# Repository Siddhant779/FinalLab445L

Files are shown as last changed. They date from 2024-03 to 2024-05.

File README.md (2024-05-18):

Review Assignment Due Date (https://classroom.github.com/a/83gqoQ2Z)
# ECE445L Final Lab
## Link to award won - Spring 2024
https://github.com/ECE445L/ECE445L-Winners
## Deliverables

The deliverables folder should contain documentation about your project as
outlined in the lab documents.

## HW

The hw folder should contain your schematic and board files for your PCB or
circuits. In labs 3-11, you will be creating schematics for your circuit
in EAGLE. A setup tutorial can be found
[here](https://www.shawnvictor.net/autodesk-eagle.html).

## SW

The sw folder should contain your application firmware and software written for
the lab. The sw/inc folder contains firmware drivers written for you by
Professor Valvano. Feel free to write your own (in fact, in some labs, you may
be required to write your own).

You can place any other source files in the sw/ folder. TAs will look at the
files you create and/or modify for software quality and for running your
project.

## Resources

A couple files are provided in the Resources folder so you don't have to keep
searching for that one TI document. Some of them are immediately useful, like
the TM4C datasheet. Others may be useful for your final project, like the
TM4C_System_Design_Guidelines page.

## Git and Github

We will extensively use Git and Github for managing lab projects. This makes it
easier for TAs to grade and help debug the project by allowing the students to
see commit histories, maintain a common project structure, collaborate with
partners, merge different codebases, and to debug work.

Two common ways of using Git and Github are [Github Desktop](https://desktop.github.com/) and the [command line](https://git-scm.com/downloads). [Tutorials](https://dev.to/mollynem/git-github--workflow-fundamentals-5496) are also abundant on the net for you to peruse. We've provided a cheatsheet for git in the Resources folder.

It is highly recommended to make the most out of Git, even if you've never used
it before. Version control will save you a lot of suffering, and tools like Git
or SVN are ubiquitous in the industry.

## Lab Report

Following the lab doc provided at the root of this project, the TAs request you
submit a lab report in Microsoft Word (or Pages, if you're a Mac user). Please
name it `EID_lab_LAB_NUMBER_report.pdf`. Templates are provided in the root dir.

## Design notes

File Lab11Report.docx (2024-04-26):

Name: __ Prithvi Senthilkumar, Joon Song, Siddhant Pandit, Wyatt Cole

EID: __ ps33536_hjs2235_shp695_wtc534

Semester: Spring 2024

Course: ECE445L

A) Objectives:

1. In a few sentences, describe the purpose of the lab.

Purpose is to design an embedded system that can fit in an enclosure. We are building the Tpod, which is an Ipod like music player that stores song in an SD card, plays songs through headphones, and has touch display and can send messages over wifi. This lab builds the PCB for the system

B) Hardware Design Deliverables:

1. N/A

C) Software Design Deliverables:

1. I have pushed my project to GitHub for grading (Yes/No):
2. Deliverable 1: System design diagram of the modules created.

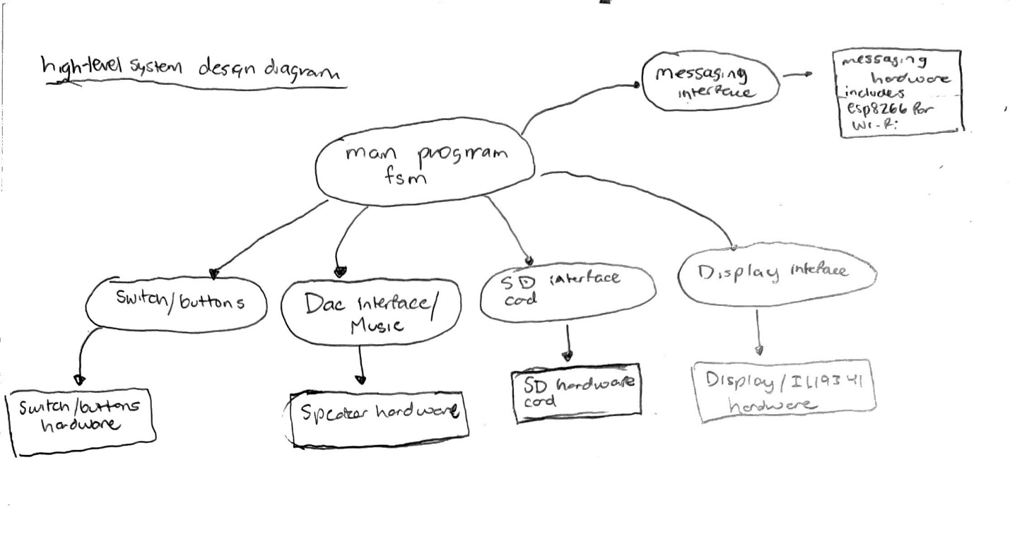
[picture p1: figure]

D) General Deliverables:

1. Deliverable 2: Software Tests

Based on our design diagram, we had separate tests for each module. For the dis-play, to test our initialization function we built a basic circuit to connect our TM4C to the ILI9341 screen, and see if basic functions such as drawing pixels work on the screen. After that, we added draw and outString functions for our project. For the SD card, we wrote basic code for reading from a txt file and outputting the values that we read on the screen. Furthermore, for sound we first tested the sound with individual notes, then moved on to reading from a music array that was set as a constant within the program. Lastly for mes-saging, we tested the server by using dummy clients and sending messages. Along that same line we tested sending from the TM4C by matching the message to what was received by the server and what was sent by the TM4C. We tested receiving by matching the mes-sage that was displayed by the TM4C to what was sent by the server. For integration tests, we used the same tests for each module as we integrated each module with each other. We first integrated display with SD card, then sound, then buttons and last-ly messaging, and tested each module with the tests described above at every step.

2. Deliverable 3: Hardware Tests

Tested all the board voltages with a multimeter to make sure power worked.

Tested audio software test on PCB to make sure headphone jack worked.

Tested wifi communication on PCB to make sure it worked same as breakboard.

Tested potentiometer to make sure it worked for ADC on PCB.

Multiple iterations of enclosure to make sure PCB fits and buttons can be pressed

3. Deliverable 4: Power consumption

Launchpad Base – 86 mA * 5V = 430 mW

Screen - 25 mA active * 3.3V = 75 mW

Music – 14-144 mA volume range * 5V = 70-720 mW

ESP –78 mA active * 3.3V = 257.4 mW active

Total – 1.482W when music active, .832.4 W when music passive

4. Deliverable 5 (10pt EC): Characterization of the system N/A

E) Analysis and Discussion Questions:

1. N/A

Lab 6 report ECE445L

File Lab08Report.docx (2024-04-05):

Name: __ Prithvi Senthilkumar, Joon Song, Siddhant Pandit, Wyatt Cole

EID: __ ps33536_hjs2235_shp695_wtc534

Semester: Spring 2024

Course: ECE445L

A) Objectives:

1. In a few sentences, describe the purpose of the lab.

Purpose is to design an embedded system that can fit in an enclosure. We are building the Tpod, which is an Ipod like music player that stores song in an SD card, plays songs through headphones, and has touch display and can send messages over wifi. This lab builds the PCB for the system

B) Hardware Design Deliverables:

1. Deliverable 1: Using KiCad, create a schematic for your design. Include a screenshot in the space below.

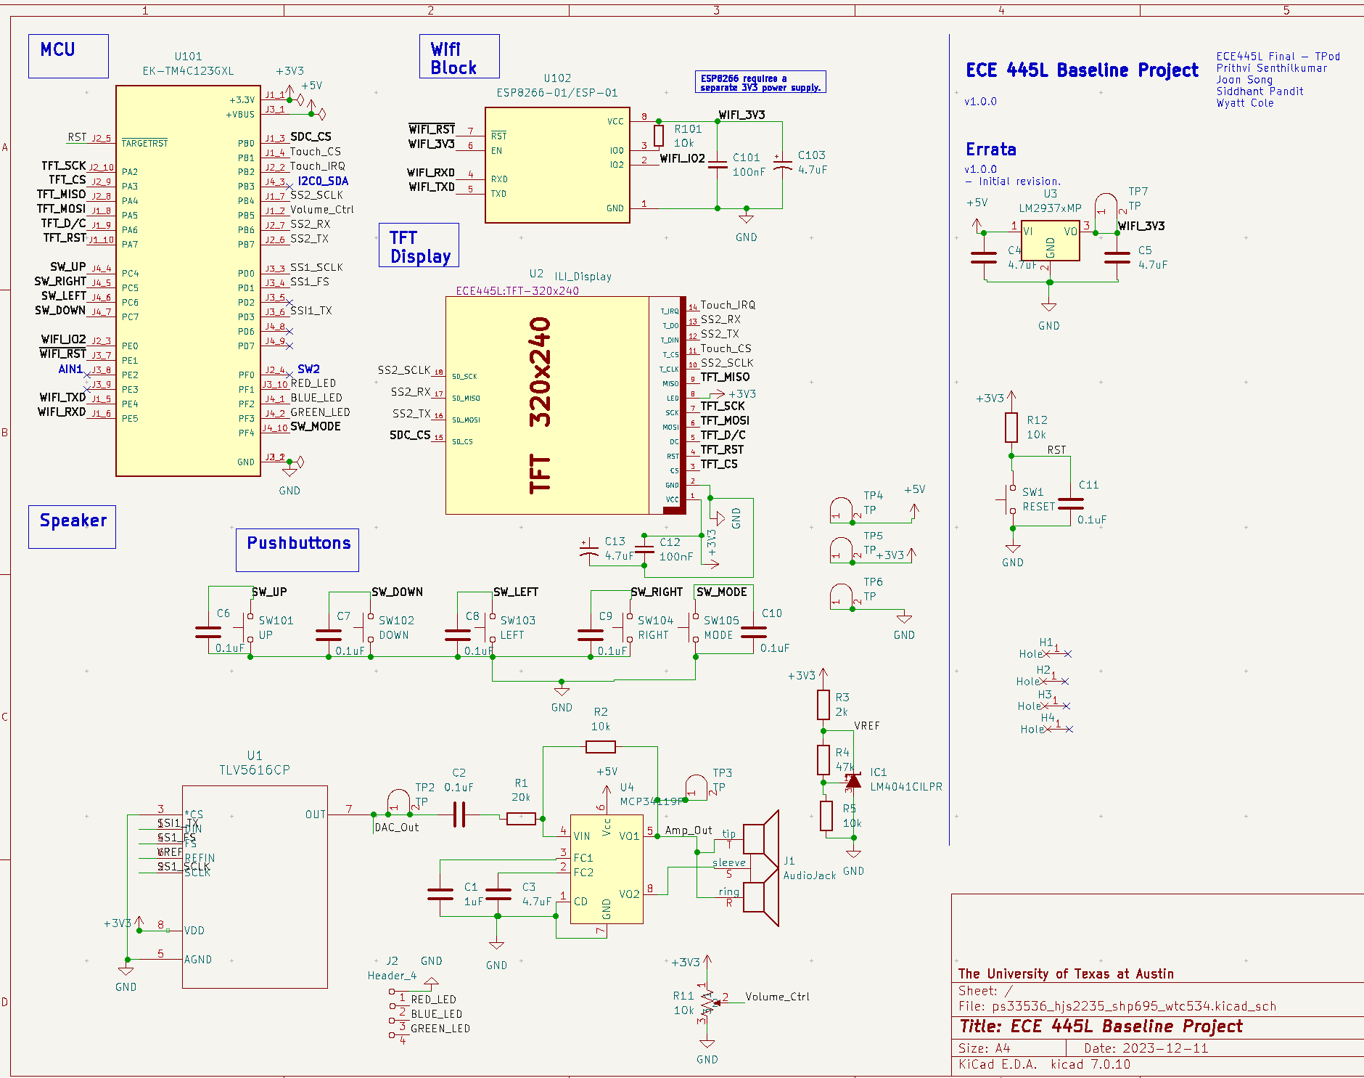
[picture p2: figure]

2. Deliverable 2: Using KiCad, create a Layout for your design. Include a screenshot in the space below.

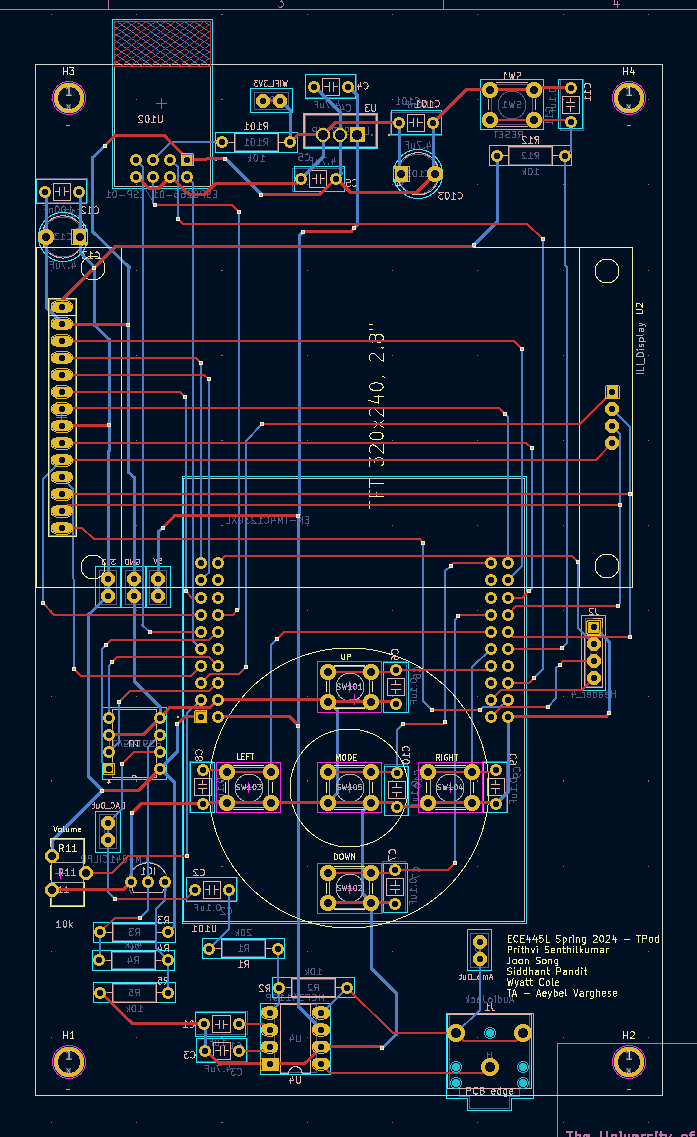
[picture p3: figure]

C) Software Design Deliverables:

1. I have pushed my project to GitHub for grading (Yes/No):
2. Deliverable 3: System design diagram of the modules created.

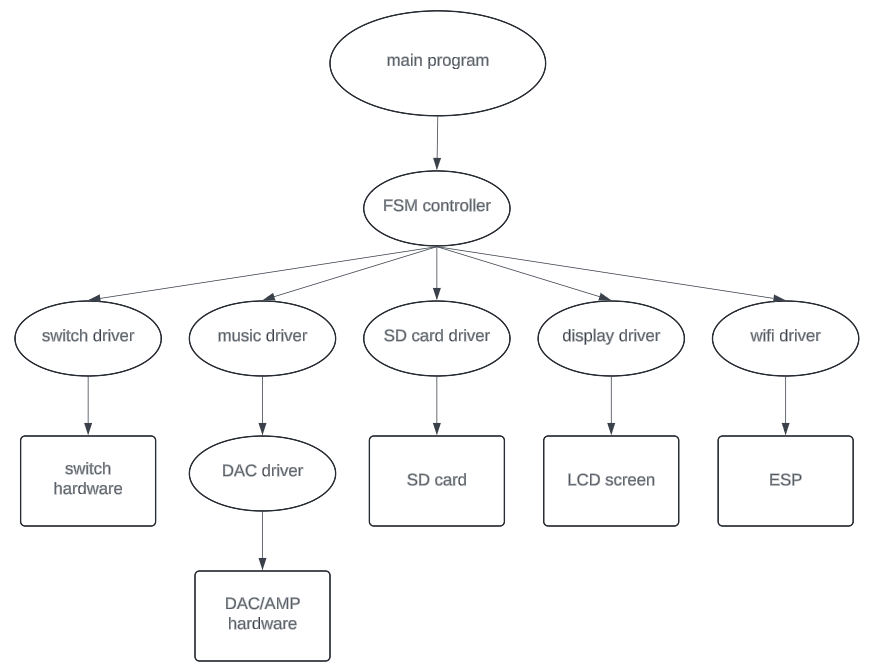
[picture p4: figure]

D) General Deliverables:

1. Deliverable 4: Total cost estimate
2. I have updated the bill of materials (Yes/No):
4. Out of pocket costs: $21
5. Adjusted competition costs: $21
6. Deliverable 5: Description of tests added for lab 8

Wifi test – connect ESP to python server to test sending and receiving messages

Sound test – Testing potentiometer ADC input to control volume through software

LCD display test – Write drivers to display to create lines and text

Integration test – Make all 3 of these work at same time

7. Deliverable 6 (10pt EC): Discrete IC usage N/A
8. Deliverable 7 (10pt EC): Characterization of the system N/A

E) Analysis and Discussion Questions:

1. What is the required naming scheme of the PCB submitted to us for review and ordering?

ps33536_hjs2235_shp695_wtc534.kicad_pro

and same for pcb and schematic files

Lab 8 report ECE445L

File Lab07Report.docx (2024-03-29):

Name: __Prithvi Senthilkumar, Joon Song, Siddhant Pandit, Wyatt Cole

EID: __ps33536_hjs2235_shp695_wtc534

Semester: Spring 2024

Course: ECE445L

A) Objectives:

1. In a few sentences, describe the purpose of the lab:

Purpose is to design an embedded system that can fit in an enclosure. We are building the Tpod, which is an Ipod like music player that stores song in an SD card, plays songs through headphones, and has touch display and can send messages over wifi.

B) Hardware Design Deliverables:

1. Deliverable 1: Using KiCad, create a schematic for your design. Include a screenshot in the space below.

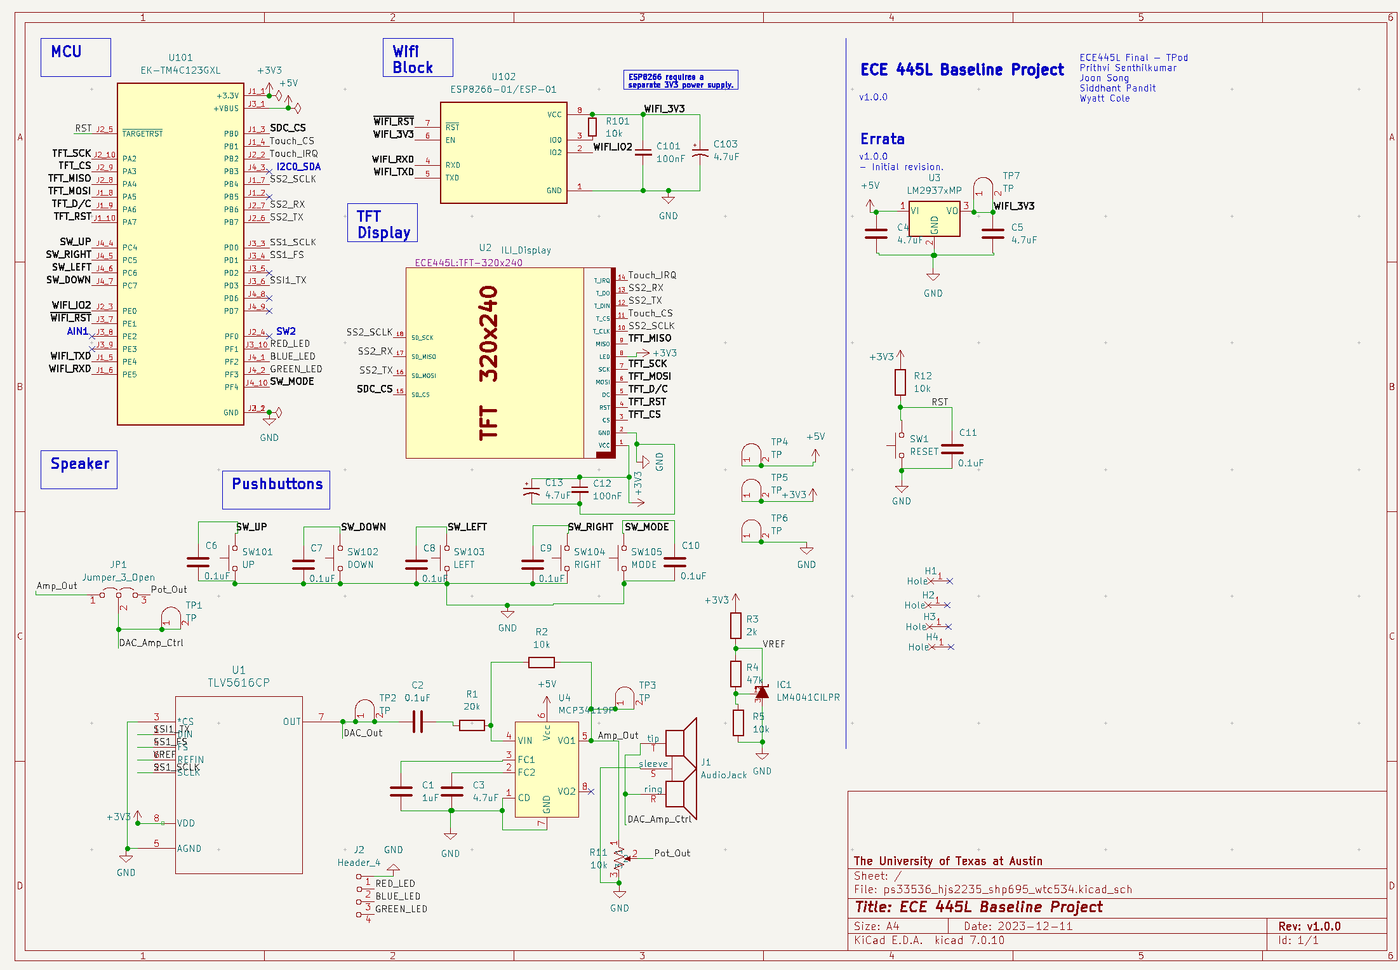
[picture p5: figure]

2. Deliverable 2: Using KiCad, create a Layout for your design. Include a screenshot in the space below.

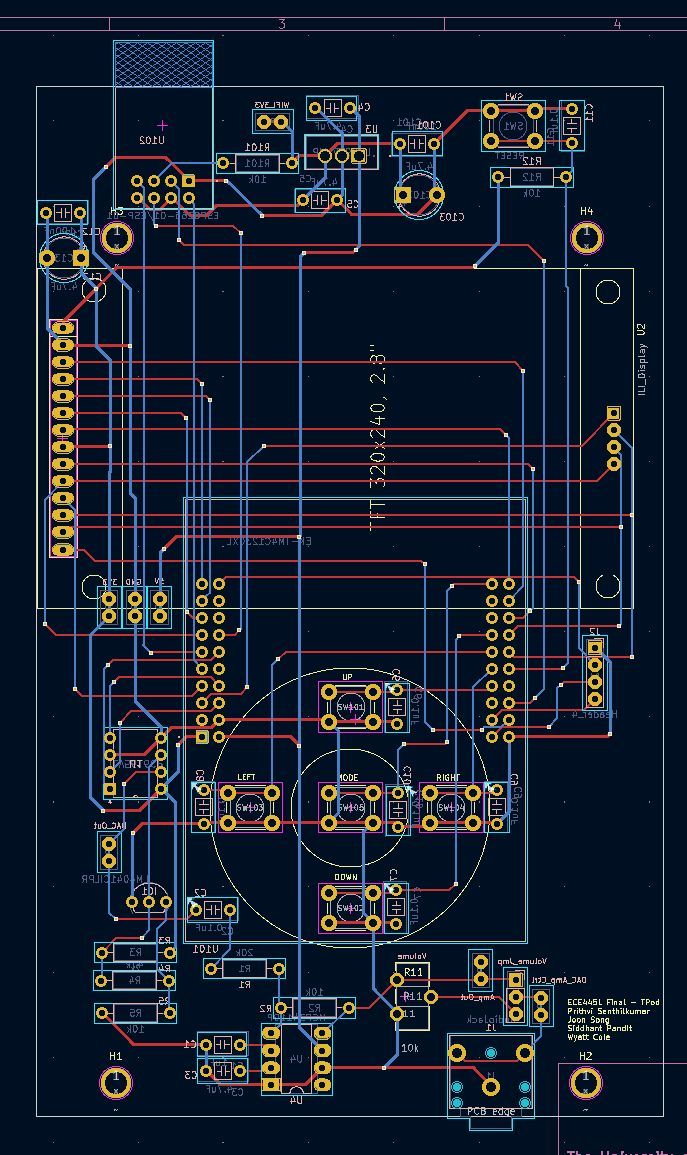
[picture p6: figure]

C) Software Design Deliverables:

1. I have pushed my project to GitHub for grading (Yes/No):
2. Deliverable 3: System design diagram of the modules created.


D) Deliverables:

1. Deliverable 4: Total cost estimate

I have updated the bill of materials (Yes/No):

Out of pocket costs: $21

Adjusted competition costs: $21

2. Deliverable 5: Estimated current usage

Launchpad Base – 86 mA

Screen - 25 mA active

Music – 14-144 mA volume range

ESP –78 mA active

Total – 333 mA max

3. Deliverable 6 (5pt EC): TIW Training

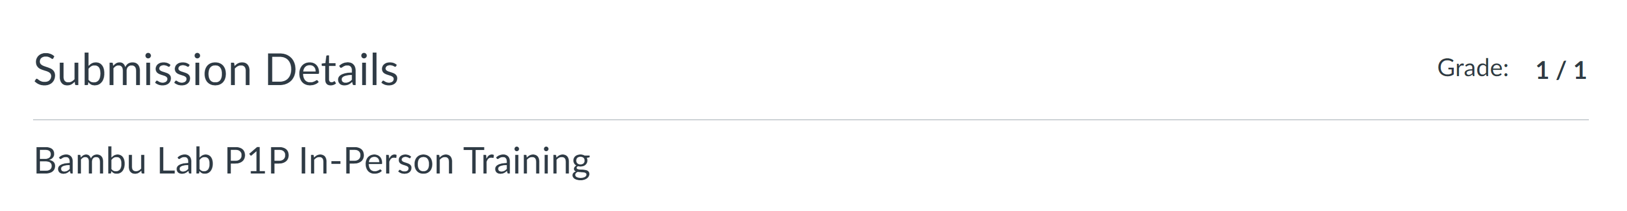
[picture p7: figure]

4. Deliverable 7 (10pt EC): Discrete IC usage N/A
5. Deliverable 8 (10pt EC): Characterization of the system N/A

E) Analysis and Discussion Questions:

1. How did you debug your system? How intrusive was it?

We mostly focused on isolating the sound and button modules, we wrote a tester main to make sure we could read from a wav file to play music, and testing button presses to make sure the controls worked. It was non-intrusive testing since we tested the functionality of the system in real time without any debugging instruments.

2. What’s the difference between unit testing, integration testing, and functional testing?

Unit testing tests individual units, integration testing tests interaction between units, functional testing is for the overall system as specified by the end user.

Lab 7 report ECE445L

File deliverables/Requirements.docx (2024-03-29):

## Project Requirements Document:

1) Overview
  a) Objectives: Why are we doing this project? What is the purpose?

Purpose is to design an embedded system that can fit in an enclosure. Test interactions of multiple HW and software modules

  b) Interactions with Existing Systems: Include this if you are connecting to another board

Will connect to another board to pass messages using TCP sockets with the ESP2866

  c) Terminology: Define domain specific terms used in the document.

Tpod – name of the embedded systems device

ILI9341 – name of the display

2) Functional Description
  a) Functionality: What will the system do precisely?

We are building the Tpod, which is an Ipod like music player that stores song in an SD card, plays songs through headphones, and has touch display and can send messages over wifi.

  b) Performance: Define the measures and describe how they will be determined.

Performance well if song can be played in real time, latency for display interactions is under 0.2 seconds, wifi can send messages through the server within 10 seconds.

  c) Usability: Describe the interfaces. Be quantitative if possible

Wifi interface will interact with server to handle message passing.

Menu interface to navigate features across the Tpod

5 button interface to navigate the menu

Possible touch screen interface to navigate menu

SD card interface to store songs to play

Audio interface with DAC, amp, and headphone jack to play the stored songs

3) Deliverables
  a) Roles and Responsibilities: Who will do what? What is the purpose?

Prithvi does PCB and enclosure

Wyatt does music, sound and buttons

Siddhant does ILI9341 display drivers and SD card interface

Joon does wifi communication protocols and message server

  b) Reports: Simply state the reports for Labs 7 and 11 will be written

Lab 7 report is written

  c) Outcomes: What are the deliverables? How do we know when it is done?

Project is done when each interface is completed and works concurrently with the menu. It is done when each module can perform together and still meet the end user latency requirements

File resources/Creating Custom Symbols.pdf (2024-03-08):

## Creating Custom Symbols

## Contents

Creating Custom Symbols | 1

Introduction

KiCad is a powerful open-source software suite for electronic design automation (EDA). It offers a comprehensive set of tools for schematic capture and PCB layout. While KiCad comes with an extensive library of symbols and footprints, there are times when you may need to create custom symbols and footprints to suit specific components or devices not available in the standard libraries or online.

Creating custom symbols allows you to represent components accurately in your schematics, while custom footprints enable precise placement and routing of PCB components.

Creating a Custom Symbol

A symbol in KiCad represents a component on your schematic. Every component on a schematic must be precisely represented to ensure the functionality and reliability of the final product. While KiCad offers a vast library of pre-made symbols, there are instances where designers encounter unique components or specialized devices not covered by the standard offerings.

To create a symbol, open the symbol editor.

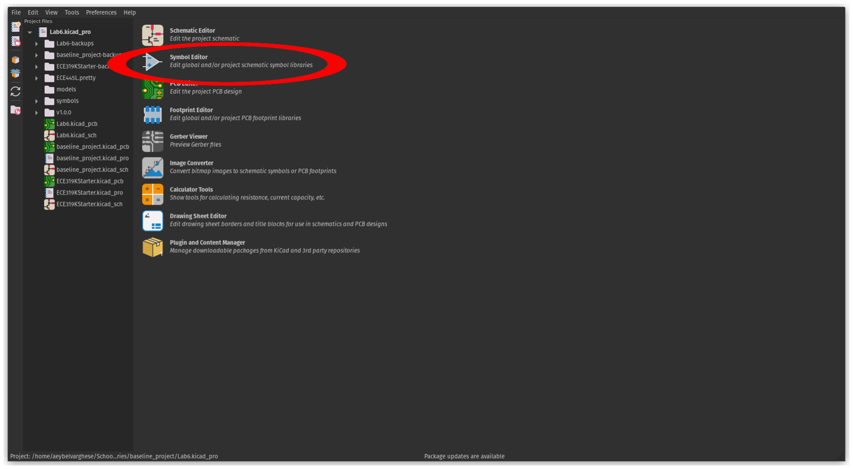
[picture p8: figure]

Figure 1: Main Menu

The KiCad Symbol Editor is a tool within the KiCad software suite specifically designed for creating and editing schematic symbols. It provides a user-friendly interface for designing graphical representations of electronic components, which are then used in schematics to illustrate circuit connections and layouts.

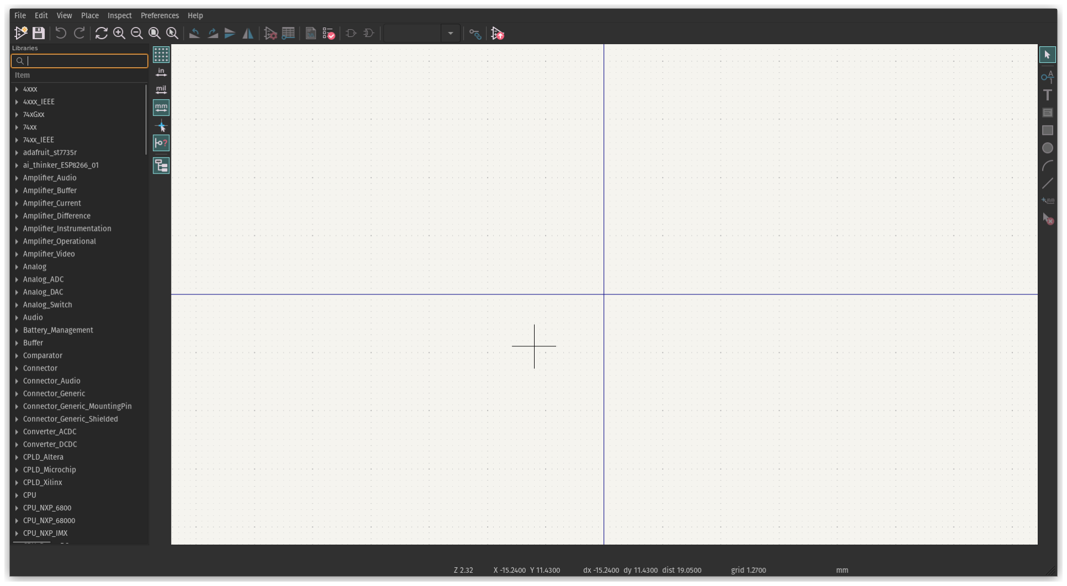
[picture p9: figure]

Figure 2: KiCad Symbol Editor

The Symbol Editor offers a graphical canvas where users can draw and manipulate schematic symbols using various drawing tools such as lines, arcs, polygons, and text boxes. The Symbol Editor allows users to save custom symbols to libraries for future use in other projects. Libraries can be organized and managed within KiCad to ensure easy access to custom symbols and efficient reuse across designs. Refer to the resource on adding libraries on more information regarding libraries.

When creating a symbol, it must be part of a library. We can either select a library to append a symbol to, or create a new library. To create a library, navigate to File → New Library, from here we can decide which symbol library table we want to add to, the global or project.

The global library table is shared amongst all your KiCad projects, while the project table is only for your currently open project. For this writeup, I am going to be adding it to the Project Table. When you press Ok, you can choose the location to save the “.kicad_sym” file which will contain your symbol library. You can choose any location you wish, although it is reccomended to have a folder dedicated for symbols organized in a reasonable matter. There is a “footprints” folder in the baseline project, and I will be storing the symbol library there. A entry in the symbol library table will be automatically made.

With a library selected in the left pane, press the “New Symbol Icon” or the Keyboard shortcut “N” to create a new symbol

Figure 3: Creating a symbol in the toolbar

Provide a name for the symbol, I am going to be creating a symbol for the MPU6050, (https://invensense.tdk.com/wp-content/uploads/2015/02/MPU-6000-Datasheet1.pdf) a IMU (Intertial Measurement Unit) from TDK InvenSense.

Creating symbols in KiCad involves designing graphical representations of electronic components to be used in schematics. Referring to datasheets during this process is crucial for accurately capturing the component’s electrical characteristics and pin configurations.

Referring to the pinout, we notice there are three categories of pins for this specific IC: power, communi-cation, and miscellaneous pins. We want to include all of these in our symbol. KiCad provides tools in the side toolbar to draw basic geometric shapes and describe pins.

Lets start by using the box tool to define the shape of our symbol.

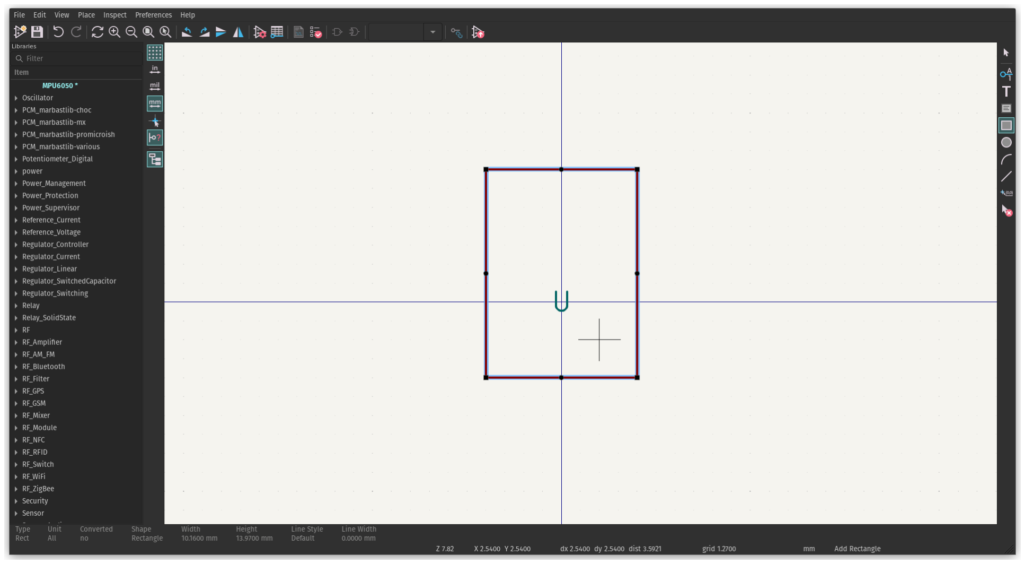
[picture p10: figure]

Figure 4: Box in Symbol Editor

With the shape of our pin assigned lets start adding pins. Select the “Add a Pin” button on the side toolbar, or press “P”.

When you press “Add a pin” in the KiCad Symbol Editor, you are prompted with several options to configure the properties of the pin being added to the symbol. These options allow you to define the electrical characteristics and behavior of the pin within the schematic symbol.

1. Name: This field allows you to specify the name of the pin, which is typically a descriptive label indicating the function or purpose of the pin within the component. Refer to the datasheet of the component for the name
2. Number: Here, you can assign a unique number to the pin. Pin numbers are used to identify individual pins within the symbol and are often based on the component’s datasheet or industry standards.
3. Orientation: This option determines the direction in which the pin is oriented within the symbol. You can choose from various orientations such as left, right, up, down.
4. Length: Specifies the length of the pin’s graphical representation within the symbol. This helps to visually distinguish pins of different lengths and aids in aligning pins with their corresponding connection points in the schematic.
5. Electrical Type: Defines the electrical characteristics of the pin, such as whether it is an input, output, bidirectional, power, or other special types. Selecting the appropriate electrical type ensures correct behavior during circuit simulation and layout as well as good for organization.
6. Visible: Determines whether the pin is visible or hidden in the symbol. Hidden pins are often used for internal connections or other purposes where the pin should not be displayed on the schematic.
7. Pin Function: This option allows you to specify additional information about the pin’s function or behavior, such as whether it is a clock input, reset signal, or other specialized function. This information aids in documentation and understanding the purpose of each pin within the symbol.

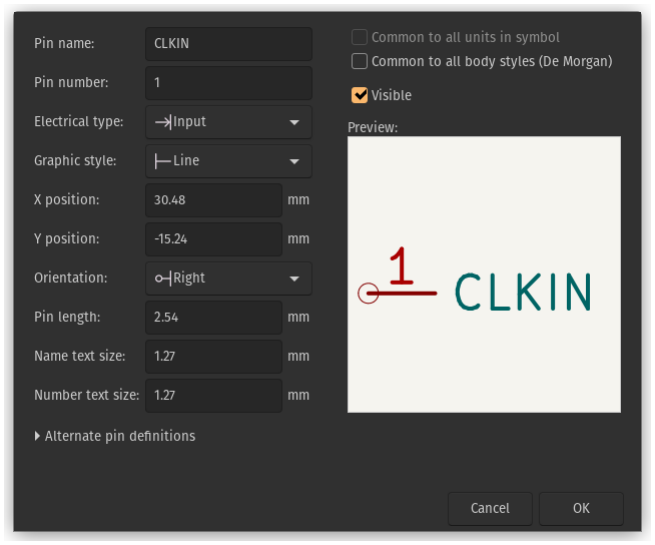
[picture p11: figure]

Figure 5: Describing a pin

Once we submit the options for the pin, we can place the pin down on our symbol.

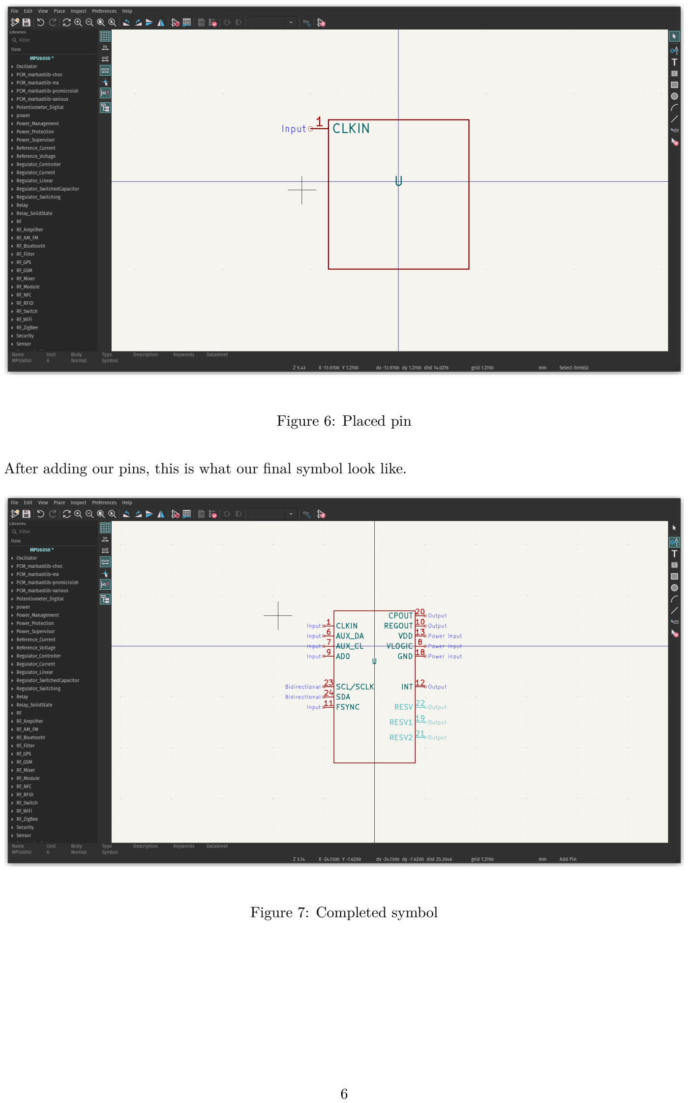
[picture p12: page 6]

Figure 6: Placed pin

After adding our pins, this is what our final symbol look like.

Figure 7: Completed symbol

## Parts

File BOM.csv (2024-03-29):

Source: | C:\Keil_v5\ValvanoWareTM4C123v5\ece-445l-lab-7-8-11-sp24-ps33536-hjs2235-shp695-wtc534\hw\baseline_project\baseline_project.kicad_sch
Date: | 3/28/2024 17:34
Tool: | Eeschema 7.0.10
Generator: | C:\Program Files\KiCad\7.0\bin\scripting\plugins/bom_csv_grouped_by_value.py
Component Count: | 50
Collated Components:
Item | Qty | Reference(s) | Value | LibPart | Footprint | Datasheet | DNP | Cost | Distributor | Manufacturer | P/N
1 | 1 | C1 | 1uF | Device:C | ECE445L:C_Axial_200mil | ~ | Checkout | $0
2 | 7 | C2, C6, C7, C8, C9, C10, C11 | 0.1uF | ECE445L:C | ECE445L:C_Axial_200mil | ~ | Checkout | $0
3 | 3 | C3, C4, C5 | 4.7uF | Device:C | ECE445L:C_Axial_200mil | ~ | Checkout | $0
4 | 2 | C101, C102 | 100nF | Device:C_Small | ECE445L:C_Axial_200mil | ~ | Checkout | $0
5 | 2 | C103, C104 | 4.7uF | Device:C_Polarized_Small_US | ECE445L:CP_Radial_Tantal200mil | ~ | Checkout | $0
6 | 4 | H1, H2, H3, H4 | ~ | ECE445L:MountingHole | ECE445L:MountingHole_4_40 |  | Checkout | $0
7 | 1 | IC1 | LM4041CILPR | ti_LM4041CILPR:LM4041CILPR | ECE445L:ti_LM4041CILPR | https://www.ti.com/general/docs/suppproductinfo.tsp?distId=26&gotoUrl=https://www.ti.com/lit/gpn/lm4041a12 | Checkout | $0 | Mouser | Texas Instruments | LM4041CILPR
8 | 1 | J1 | AudioJack | ECE445L:HeadphoneJack | ECE445L:Jack_3.5mm_CUI_SJ1-3523N_Horizontal | ~ | Checkout | $0
9 | 1 | J2 | Header_4 | ECE445L:Header_4 | ECE445L:PinHeader_1x04_P2.54mm_Vertical | ~ | Checkout | $0
10 | 1 | JP1 | Jumper_3_Open | ECE445L:Jumper_3_Open | ECE445L:PinHeader_1x03_P2.54mm_Vertical | ~ | Checkout | $0
11 | 1 | R1 | 20k | Device:R | Resistor_THT:R_Axial_DIN0207_L6.3mm_D2.5mm_P10.16mm_Horizontal | ~ | Checkout | $0
12 | 3 | R2, R5, R12 | 10k | Device:R | Resistor_THT:R_Axial_DIN0207_L6.3mm_D2.5mm_P10.16mm_Horizontal | ~ | Checkout | $0
13 | 1 | R3 | 2k | Device:R | Resistor_THT:R_Axial_DIN0207_L6.3mm_D2.5mm_P10.16mm_Horizontal | ~ | Checkout | $0
14 | 1 | R4 | 47k | Device:R | Resistor_THT:R_Axial_DIN0207_L6.3mm_D2.5mm_P10.16mm_Horizontal | ~ | Checkout | $0
15 | 1 | R11 | 10k | ECE445L:Potentiometer | ECE445L:Potentiometer |  | Checkout | $0
16 | 1 | R101 | 10k | Device:R_Small | Resistor_THT:R_Axial_DIN0207_L6.3mm_D2.5mm_P10.16mm_Horizontal | ~ | Checkout | $0
17 | 1 | SW1 | RESET | Switch:SW_Push | Button_Switch_THT:SW_PUSH_6mm | ~ | Checkout | $0
18 | 1 | SW101 | UP | Switch:SW_Push | Button_Switch_THT:SW_PUSH_6mm | ~ | Checkout | $0
19 | 1 | SW102 | DOWN | Switch:SW_Push | Button_Switch_THT:SW_PUSH_6mm | ~ | Checkout | $0
20 | 1 | SW103 | LEFT | Switch:SW_Push | Button_Switch_THT:SW_PUSH_6mm | ~ | Checkout | $0
21 | 1 | SW104 | RIGHT | Switch:SW_Push | Button_Switch_THT:SW_PUSH_6mm | ~ | Checkout | $0
22 | 1 | SW105 | MODE | Switch:SW_Push | Button_Switch_THT:SW_PUSH_6mm | ~ | Checkout | $0
23 | 7 | TP1, TP2, TP3, TP4, TP5, TP6, TP7 | TP | ECE445L:Testpoint | ECE445L:Testpoint_1x02_P2.54mm | ~ | Checkout | $0
24 | 1 | U1 | TLV5616CP | ti_TLV5616CP:TLV5616CP | ECE445L:ul_TLV5616CP | TLV5616CP | Checkout | $0
25 | 1 | U3 | LM2937xMP | Regulator_Linear:LM2937xMP | ECE445L:LM2937 | http://www.ti.com/lit/ds/symlink/lm2937.pdf | Checkout | $0
26 | 1 | U4 | MCP34119P | ECE445L:MCP34119P | ECE445L:DIP-8_W7.62mm_LongPads | https://users.ece.utexas.edu/~valvano/Datasheets/MC34119.pdf | Checkout | $0 | N/A | Motorola | MC34119P
27 | 1 | U101 | EK-TM4C123GXL | ti_EKTM4C123GXL:EK-TM4C123GXL | ECE445L:ti_EKTM4C123GXL | https://www.ti.com/lit/ds/symlink/tm4c123gh6pm.pdf?ts=1693244962384 | Checkout | $0 | Mouser | Texas Instruments | EK-TM4C123GXL
28 | 1 | U102 | ESP8266-01/ESP-01 | ai_thinker_ESP8266_01:ESP8266-01/ESP-01 | ECE445L:ai_thinker_ESP8266_01 | https://nurdspace.nl/ESP8266 | Checkout | $0 | Mouser | SparkFun | WRL-17146
29 | 1 | U103 | ILI9341 | Hosyond | ECE445L:adafruit_st7735r |  | Amazon | $15 | Mouser | Adafruit | 358
 | 1 | SD Card | SD Card |  |  |  | Amazon | $6

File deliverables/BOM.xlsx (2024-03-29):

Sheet: Parts
Bill of Materials |  |  | 2022-03-10 | "not free" means you have to buy it |  | "free sample" means you have to order it
EE445L Spring 2022 |  |  | EE445L pays for the PCB | "Cabinet means in one of the six black cabinets in professsor's office (bring a print out of your SCH")
 |  |  |  | "Professor" means ask your professor quantity and style will vary (bring a print out of your SCH circuit)
Qty Note | REF DES Note (http://projects.ece.utexas.edu/valvano/wiki/doku.php?id=pcbartist:schematics) |  |  | "Box means in box in your professor's office (bring a print out of your SCH circuit)
Quantity | REF DES | Type | Description | Manufacturer | Mfg. P/N | Distributor | P/N | Unit cost | Cost |  | Where to get it? | Inventory
0 |  | ASM | 8-ohm speaker |  |  | AllElectronics | SK-840 | $0.60 | $0.00 | Speaker | professor | https://www.allelectronics.com/item/sk-840/speaker-8-ohm-40mm/1.html
0 |  | ASM | 9V battery snap, T-type |  |  | AllElectronics | BST-61 | $0.50 | $0.00 | Jumper2 | Box
0 |  | ASM | Black case, 5.5" x 2.6" x 1.1" | Hammond | 1593YALBK | Mouser | 546-1593YALBK | $8.50 | $0.00 |  |  | http://www.hammondmfg.com/pdf/1593Y.pdf
0 |  | ASM | Black Case 5.620" x 3.250" X 1.500" | Serpac | 151 | Digikey | SR151B-ND | $10.88 | $0.00 |  | professor
0 |  | ASM | Black case, 7.5" by 4.3" by 2.2" | Hammond | 1591ESBK | Mouser | 546-1591ES-BK | $8.71 | $0.00 |  | Box | http://www.hammondmfg.com/pdf/1591E.pdf
0 |  | ASM | Electret microphone | Panasonic |  | AllElectronics | MIKE-79 | $0.50 | $0.00 | electret | Cabinet
0 |  | CAP | Ceramic, X7R, 20%, 1 uF |  |  | Jameco | 81509 | $0.35 | $0.00 | Ceramic0.2 | Cabinet
0 |  | CAP | Ceramic, Z5U, -20/+80%, 0.47 uF | Kemet | C320C474M5U5TA | Digikey | 399-4309-ND | $0.40 | $0.00 | Ceramic | Cabinet
0 |  | CAP | Ceramic, Z5U, -20/+80%, 0.1 uF |  |  | Digikey | 399-4151-ND | $0.04 | $0.00 | Ceramic | Cabinet
0 |  | CAP | Ceramic, Z5U, -20/+80%, 0.033 uF |  |  | Digikey | 399-4298-ND | $0.40 | $0.00 | Ceramic | Cabinet
0 |  | CAP | Ceramic, Z5U, -20/+80%, 0.027uF |  |  |  |  | $0.40 | $0.00 | Ceramic | Cabinet
0 |  | CAP | Ceramic, Z5U, -20/+80%, 0.01 uF |  |  | Digikey | 399-4148-ND | $0.40 | $0.00 | Ceramic | Cabinet
0 |  | CAP | Ceramic, Z5U, -20/+80%, 4.7 nF |  |  | Digikey | 399-4188-ND | $0.40 | $0.00 | Ceramic | Cabinet
0 |  | CAP | Ceramic, Z5U, -20/+80%, 2.2 nF |  |  |  |  | $0.40 | $0.00 | Ceramic | Cabinet
0 |  | CAP | Ceramic, Z5U, -20/+80%, 1 nF |  |  |  |  | $0.40 | $0.00 | Ceramic | Cabinet
0 |  | CAP | Ceramic Z5U, -20/+80%, 470 pF |  |  |  |  | $0.03 | $0.00 | Ceramic | Cabinet
0 |  | CAP | Ceramic Z5U, -20/+80%, 330 pF |  |  |  |  | $0.03 | $0.00 | Ceramic | Cabinet
0 |  | CAP | Ceramic Z5U, -20/+80%, 220 pF |  |  |  |  | $0.03 | $0.00 | Ceramic | Cabinet
0 |  | CAP | Ceramic Z5U, -20/+80%, 100 pF |  |  |  |  | $0.03 | $0.00 | Ceramic | Cabinet
0 |  | CAP | Ceramic Z5U, -20/+80%, 22 pF |  |  |  |  | $0.03 | $0.00 | Ceramic | Cabinet
0 |  | CAP | Ceramic C0G, 10%, 10 pF | Murata 50V 5% | RDE5C1H100J0P1H03B | Digikey | 490-8629-ND | $0.31 | $0.00 | Ceramic | Cabinet | not required, we expect most students will create a system with the LaunchPad
0 |  | CAP-Tant | Tantalum, 16V, 20% 2.2 uF | AVX Corporation | TAP225M016CCS | Digikey | 478-8819-ND | $0.29 | $0.00 | tantalum | Cabinet
0 |  | CAP-Tant | Tantalum, 16V, 10% 4.7 uF |  |  | Digikey | 478-1904-ND | $0.22 | $0.00 | tantalum | Cabinet
0 |  | CAP-Tant | Tantalum, 20V, 10%, 1 uF |  |  | Digikey | 478-1833-ND | $0.32 | $0.00 | tantalum | Cabinet
0 |  | CAP-Tant | Tantalum, 20V 10%, 10uF |  |  | Digikey | 478-1840-ND | $0.56 | $0.00 | tantalum | Cabinet
0 |  | CAP-Tant | Tantalum, 35V, 10%, 0.47 uF |  |  | Jameco | 33531 | $0.19 | $0.00 | tantalum | Cabinet
0 |  | CAP-Elec | Electrolytic, 16V, 100 uF, cap 20%, ESR=20mV |  |  | Mouser | 661-APSF160E101MF05S | $0.38 | $0.00 | tantalum | Cabinet
0 |  | CON | 2 to 40 pin 0.1 in header (price per pin) |  |  | AllElectronics | SHS-40 | $0.02 | $0.00 | Jumper2 | Cabinet | https://www.allelectronics.com/item/shs-40/1-x-40-header-0.1-spacing/1.html
0 |  | CON | 2-pin shrouded header (mates with SBC-2) |  |  | AllElectronics | SBH-2 | $0.10 | $0.00 | Jumper2 | Cabinet | https://www.allelectronics.com/item/sbh-2/header-for-small-battery-conn-2.5mm-spacing/1.html
0 |  | CON | 2-pin battery cable (mates with SBH-2) |  |  | AllElectronics | SBC-2 | $0.27 | $0.00 | goes with SBH-2 | Cabinet | https://www.allelectronics.com/item/sbc-2/small-battery-connector-2.5mm-spacing/1.html
0 |  | CON | 2-pin shorting jumper, attaches to 0.1" male-male header | Harwin | M7581-05 | Mouser | 855-M7581-05 | $0.11 | $0.00 | goes with Jumper2 | Cabinet
0 |  | CON | Test point, black | Keystone Electronics | 5001 | Digikey | 36-5001K-ND | $0.23 | $0.00 | testpoint | Cabinet
0 |  | CON | Test point, orange | Keystone Electronics | 5003 | Digikey | 36-5003K-ND | $0.23 | $0.00 | testpoint | Cabinet
0 |  | CON | Test point, yellow | Keystone Electronics | 5004 | Digikey | 36-5004K-ND | $0.23 | $0.00 | testpoint | Cabinet
0 |  | CON | Test point, white | Keystone Electronics | 5002 | Digikey | 36-5002K-ND | $0.23 | $0.00 | testpoint | Cabinet
0 |  | CON | Test point, blue | Keystone Electronics | 5117 | Digikey | 36-5117-ND | $0.23 | $0.00 | testpoint | Cabinet
0 |  | CON | Test point, green | Keystone Electronics | 5116 | Digikey | 36-5116-ND | $0.23 | $0.00 | testpoint | Cabinet
0 |  | CON | Test point, red | Keystone Electronics | 5000 | Digikey | 36-5000K-ND | $0.23 | $0.00 | testpoint | Cabinet
0 |  | CON | 10-pin female connector | SamTec | BCS-110-L-S-TE | Digikey | SAM1011-10-ND | $1.98 | $0.00 |  | Cabinet
0 |  | CON | Socket for micro SD card | Molex | 473340001 | Digikey | WM3288CT-ND | $4.02 | $0.00 | MicroSD Slot | Cabinet | do not use, rather included on ST7735
0 |  | CON | USB Mini-B socket, board mount, surface mount | Molex | 56579-0576 | Mouser | 538-56579-0576 | $2.46 | $0.00 | USB_Mini-B | Cabinet
0 |  | CON | Micro USB Type B, surface mount | Hirose Connector | ZX62D-B-5PA8(30) | Mouser | 798-ZX62D-B-5PA830 | $0.47 | $0.00 | USB_Micro-B | Cabinet
0 |  | CON | USB Mini-B socket, board mount, through hole | Molex | 54819-0519 | Digikey | WM17115-ND | $0.65 | $0.00 | USB_Mini-B | Cabinet
0 |  | CON | BoosterPack connector | FCI | 67996-220HLF | Mouser | 609-3243-ND | $0.26 | $0.00 | BoosterPack | Cabinet
0 |  | CON | Logic Analyzer connector | FCI | 68021-208HLF | Digikey | 609-3344-ND | $0.27 | $0.00 | LogicAnalyzer | Cabinet
0 |  | CON | JTAG 1 by 5 male header |  |  |  |  | $0.29 | $0.00 | JTAG | Cabinet
0 |  | CON | 10 pin 2mm socket for Xbee (need two) | SamTec | SQT-110-01-F-S | Digikey | SAM9989-ND | $2.70 | $0.00 | XbeeModule | Cabinet
0 |  | CPU | TM4C123GH6PM 64-pin LQFP | TI | TM4C123GH6PMI | Mouser | 595-TM4C123GH6PMI | $11.55 | $0.00 | TM4C123GH6PM |  | not required, we expect most students will create a system with the LaunchPad
0 |  | CRYS | NX5032GA-16.000000 | NDK | NX5032GA-16.000000 | Digikey | 644-1037-1-ND | $0.51 | $0.00 | XTAL/NX5032 | Cabinet | not required, we expect most students will create a system with the LaunchPad
0 |  | DIODE | 1N914 diode | Fairchild | 1N914 | Digikey | 1N914B-ND | $0.05 | $0.00 | 1N914 | Cabinet
0 |  | IC | LM2937 3.3 V regulator TO220, 500mA | TI | LM2937ET-3.3/NOPB | Digikey | LM2937ET-3.3-ND | $1.17 | $0.00 | LM2937-3.3 | Cabinet
0 |  | IC | LP2950 3.3V regulator, 100 mA TO-92 | TI | LP2950-33LPRE3 | Digikey | 296-31455-1-ND | $0.19 | $0.00 | LP2950-CZ-3.3 | Cabinet
0 |  | IC | 78M05 500mA 5V TO-220 regulator | National | LM78M05 | Jameco | 192233 | $0.19 | $0.00 | LM7805CT | Cabinet
0 |  | IC | OPA4350 quad op amp | TI | OPA4350UA | Mouser | 595-OPA4350UA | $12.15 | $0.00 | OPA4350 | not free
0 |  | IC | TLV5616 12-bit DAC | TI | TLV5616CP | Mouser | 595-TLV5616CP | $10.09 | $0.00 | TLV5616 | not free
0 |  | IC | TLV5618 dual 12-bit DAC | TI | TLV5618 | Mouser | TLV5618ACP | $14.18 | $0.00 | TLV5618 | not free
0 |  | IC | INA122P instrumentation amp | TI | INA122P | Mouser | 595-INA122P | $9.09 | $0.00 | INA122 | Cabinet or free sample
0 |  | IC | OPA2350 dual op amp | TI | OPA2350PA | obsolete |  |  | $0.00 | OPA2350 | Cabinet or free sample |  |  | 1 KD
0 |  | IC | TLC2274 quad op amp | TI | TLC2274ACN | Mouser | 595-TLC2274ACN | $3.06 | $0.00 | TLC2274 | not free |  |  | 2 HD
0 |  | IC | TPA731 audio amp (pin 1 low) 700mW | TI | TPA731D | Mouser | 595-TPA731D | $2.90 | $0.00 | TPA731 | not free |  |  | 3 AD
0 |  | IC | TPA751 audio amp (pin 1 high) 700mW | TI | TPA751D | Mouser | 595-TPA751D | $2.31 | $0.00 | TPA731 | not free |  |  | 4 JD
0 |  | IC | LM4041CILPR shunt diode reference | TI | LM4041CILPR | Mouser | 595-LM4041CILPR | $1.21 | $0.00 | LM4041 | Cabinet or free sample |  |  | 5 CD
0 |  | IC | L293 Motor H bridge | TI | L293NE | Digikey | 296-9519-5-ND | $3.50 | $0.00 | L293 | Cabinet |  |  | 7 MD
0 |  | IC | 74HC595 |  |  | Jameco | 46105 | $0.40 | $0.00 |  | Cabinet |  |  | 8 ED
0 |  | IC | 74HC165 |  |  | Jameco | 45495 | $0.30 | $0.00 |  | Cabinet |  |  | 9 FD
0 |  | IC | 74HCT125N | TI | SN74HCT125N | Mouser | 595-SN74HCT125N | $0.53 | $0.00 |  | Cabinet
0 |  | IC | RS232 driver | STMicroelectronics | ST232CN | Jameco | 2001171 | $0.58 | $0.00 | ST232 | Cabinet |  |  | 0 ND
0 |  | JACK | DC Power MALE 2.1mm |  |  | Jameco | 101179 | $0.55 | $0.00 | PowerJack | Cabinet |  |  | * LD
0 |  | JACK | Stereo Jack, or audio jack |  |  | AllElectronics | MJW-12 | $0.09 | $0.00 | HeadphoneJack | Cabinet |  | 87YY3212A
0 |  | KEY | 3 by 4 common bus (D), keypad | Grayhill | 87YY3212A-506 |  |  | $2.99 | $0.00 | 87YY3212A | Box | http://docs.bgmicro.com/pdf/swt1109.pdf
0 |  | LCD | 18-bit color 128*160 1.8" TFT LCD display | Sitronix | ST7735R | Adafruit | 358 | $19.96 | $0.00 | ST7735 | not free
0 |  | LED | Green 2mA 5mm diffused | Avago Technologies | HLMP-4740 | Digikey | 516-1327-ND | $0.29 | $0.00 | LEDT1.75 | Cabinet
0 |  | LED | Red 1.6V 1mA 5mm diffused | Avago Technologies | HLMP-D150 | Digikey | 516-1323-ND | $0.29 | $0.00 | LEDT1.75 | Cabinet
0 |  | LED | Yellow 2mA 5mm diffused | Avago Technologies | HLMP-4719 | Digikey | 516-1326-ND | $0.29 | $0.00 | LEDT1.75 | Cabinet
0 |  | LED | Orange 10mA 5mm diffused | Avago Technologies | HLMP-D401 | Digikey | 516-1330-ND | $0.29 | $0.00 | LEDT1.75 | Cabinet
0 |  | LED | Blue 10mA 5mm diffused |  |  |  |  | $0.99 | $0.00 | LEDT1.75 | Cabinet | warning, the blue LEDs are very bright
0 |  | PCB | PCB plus shipping | JLCPCB |  | JLCPCB |  | $13.00 | $0.00
0 |  | POT | 20K LINEAR SLIDE POT | Bourns | PTA2043-2015CPB103 | Mouser | 652-PTA20432015CPB10 | $1.28 | $0.00 |  | Cabinet
0 |  | POT | 10 K one-turn potentiometer |  |  |  |  | $0.15 | $0.00 | SquarePot | Professor
0 |  | POT | 20 K one-turn potentiometer |  |  |  |  | $0.15 | $0.00 | SquarePot | Professor
0 |  | RES | Carbon 1/6W, 5%, 100 | Yageo | CFR-12JB-100R | Digikey | 100EBK-ND | $0.02 | $0.00 | 0.125Wresistor | Cabinet
0 |  | RES | Carbon 1/6W, 5%, 220 | Yageo | CFR-12JB-220R | Digikey | 220EBK-ND | $0.02 | $0.00 | 0.125Wresistor | Cabinet
0 |  | RES | Carbon 1/6W, 5%, 270 | Yageo | CFR-12JB-270R | Digikey | 270EBK-ND | $0.02 | $0.00 | 0.125Wresistor | Cabinet
0 |  | RES | Carbon 1/6W, 5%, 330 | Yageo | CFR-12JB-330R | Digikey | 330EBK-ND | $0.02 | $0.00 | 0.125Wresistor | Cabinet
0 |  | RES | Carbon 1/6W, 5%, 470 | Yageo | CFR-12JB-470R | Digikey | 470EBK-ND | $0.02 | $0.00 | 0.125Wresistor | Cabinet
0 |  | RES | Carbon 1/6W, 5%, 510 | Yageo | CFR-12JB-510R | Digikey | 510EBK-ND | $0.02 | $0.00 | 0.125Wresistor | Cabinet
0 |  | RES | Carbon 1/6W, 5%, 680 | Yageo | CFR-12JB-680R | Digikey | 680EBK-ND | $0.02 | $0.00 | 0.125Wresistor | Cabinet
0 |  | RES | Carbon 1/6W, 5%, 820 | Yageo | CFR-12JB-820R | Digikey | 820EBK-ND | $0.02 | $0.00 | 0.125Wresistor | Cabinet
0 |  | RES | Carbon 1/6W, 5%, 1K | Yageo | CFR-12JB-1K0 | Digikey | 1.0KEBK-ND | $0.02 | $0.00 | 0.125Wresistor | Cabinet
0 |  | RES | Carbon 1/6W, 5%, 1.2K | Yageo | CFR-12JB-1K2 | Digikey | 1.2KEBK-ND | $0.02 | $0.00 | 0.125Wresistor | Cabinet
0 |  | RES | Carbon 1/6W, 5%, 1.5K | Yageo | CFR-12JB-1K5 | Digikey | 1.5KEBK-ND | $0.02 | $0.00 | 0.125Wresistor | Cabinet
0 |  | RES | Carbon 1/6W, 5%, 1.8K | Yageo | CFR-12JB-1K8 | Digikey | 1.8KEBK-ND | $0.02 | $0.00 | 0.125Wresistor | Cabinet
0 |  | RES | Carbon 1/6W, 5%, 2.0K | Yageo | CFR-12JB-2K0 | Digikey | 2.0KEBK-ND | $0.02 | $0.00 | 0.125Wresistor | Cabinet
0 |  | RES | Carbon 1/6W, 5%, 2.2K | Yageo | CFR-12JB-2K2 | Digikey | 2.2KEBK-ND | $0.02 | $0.00 | 0.125Wresistor | Cabinet
0 |  | RES | Carbon 1/6W, 5%, 2.7K | Yageo | CFR-12JB-2K7 | Digikey | 2.7KEBK-ND | $0.02 | $0.00 | 0.125Wresistor | Cabinet
0 |  | RES | Carbon 1/6W, 5%, 3.3K | Yageo | CFR-12JB-3K3 | Digikey | 3.3KEBK-ND | $0.02 | $0.00 | 0.125Wresistor | Cabinet
0 |  | RES | Carbon 1/6W, 5%, 3.9K | Yageo | CFR-12JB-3K9 | Digikey | 3.9KEBK-ND | $0.02 | $0.00 | 0.125Wresistor | Cabinet
0 |  | RES | Carbon 1/6W, 5%, 4.7K | Yageo | CFR-12JB-4K7 | Digikey | 4.7KEBK-ND | $0.02 | $0.00 | 0.125Wresistor | Cabinet
0 |  | RES | Carbon 1/6W, 5%, 5.1K | Yageo | CFR-12JB-5K1 | Digikey | 5.1KEBK-ND | $0.02 | $0.00 | 0.125Wresistor | Cabinet
0 |  | RES | Carbon 1/6W, 5%, 5.6K | Yageo | CFR-12JB-5K6 | Digikey | 5.6KEBK-ND | $0.02 | $0.00 | 0.125Wresistor | Cabinet
0 |  | RES | Carbon 1/6W, 5%, 6.8K | Yageo | CFR-12JB-6K8 | Digikey | 6.8KEBK-ND | $0.02 | $0.00 | 0.125Wresistor | Cabinet
0 |  | RES | Carbon 1/6W, 5%, 8.2K | Yageo | CFR-12JB-8K2 | Digikey | 8.2KEBK-ND | $0.02 | $0.00 | 0.125Wresistor | Cabinet
0 |  | RES | Carbon 1/6W, 5%, 10K | Yageo | CFR-12JB-10K | Digikey | 10KEBK-ND | $0.02 | $0.00 | 0.125Wresistor | Cabinet
0 |  | RES | Carbon 1/6W, 5%, 12K | Yageo | CFR-12JB-12K | Digikey | 12KEBK-ND | $0.02 | $0.00 | 0.125Wresistor | Cabinet
0 |  | RES | Carbon 1/6W, 5%, 15K | Yageo | CFR-12JB-15K | Digikey | 15KEBK-ND | $0.02 | $0.00 | 0.125Wresistor | Cabinet | http://www.kemet.com/kemet/web/homepage/kechome.nsf/vapubfiles/F3101_GoldMax.pdf/$file/F3101_GoldMax.pdf
0 |  | RES | Carbon 1/6W, 5%, 18K | Yageo | CFR-12JB-18K | Digikey | 18KEBK-ND | $0.02 | $0.00 | 0.125Wresistor | Cabinet
0 |  | RES | Carbon 1/6W, 5%, 20K | Yageo | CFR-12JB-20K | Digikey | 20KEBK-ND | $0.02 | $0.00 | 0.125Wresistor | Cabinet
0 |  | RES | Carbon 1/6W, 5%, 22K | Yageo | CFR-12JB-22K | Digikey | 22KEBK-ND | $0.02 | $0.00 | 0.125Wresistor | Cabinet
0 |  | RES | Carbon 1/6W, 5%, 27K | Yageo | CFR-12JB-27K | Digikey | 27KEBK-ND | $0.02 | $0.00 | 0.125Wresistor | Cabinet
0 |  | RES | Carbon 1/6W, 5%, 36K | Yageo | CFR-12JB-36K | Digikey | 36KEBK-ND | $0.02 | $0.00 | 0.125Wresistor | Cabinet
0 |  | RES | Carbon 1/6W, 5%, 33K | Yageo | CFR-12JB-33K | Digikey | 33KEBK-ND | $0.02 | $0.00 | 0.125Wresistor | Cabinet
0 |  | RES | Carbon 1/6W, 5%, 39K | Yageo | CFR-12JB-39K | Digikey | 39KEBK-ND | $0.02 | $0.00 | 0.125Wresistor | Cabinet
0 |  | RES | Carbon 1/6W, 5%, 47K | Yageo | CFR-12JB-47K | Digikey | 47KEBK-ND | $0.02 | $0.00 | 0.125Wresistor | Cabinet
0 |  | RES | Carbon 1/6W, 5%, 51K | Yageo | CFR-12JB-51K | Digikey | 51KEBK-ND | $0.02 | $0.00 | 0.125Wresistor | Cabinet
0 |  | RES | Carbon 1/6W, 5%, 56K | Yageo | CFR-12JB-56K | Digikey | 56KEBK-ND | $0.02 | $0.00 | 0.125Wresistor | Cabinet
0 |  | RES | Carbon 1/6W, 5%, 68K | Yageo | CFR-12JB-68K | Digikey | 68KEBK-ND | $0.02 | $0.00 | 0.125Wresistor | Cabinet
0 |  | RES | Carbon 1/6W, 5%, 82K | Yageo | CFR-12JB-82K | Digikey | 82KEBK-ND | $0.02 | $0.00 | 0.125Wresistor | Cabinet
0 |  | RES | Carbon 1/6W, 5%, 100K | Yageo | CFR-12JB-100K | Digikey | 100KEBK-ND | $0.02 | $0.00 | 0.125Wresistor | Cabinet
0 |  | RES | Carbon 1/6W, 5%, 120K | Yageo | CFR-12JB-120K | Digikey | 120KEBK-ND | $0.02 | $0.00 | 0.125Wresistor | Cabinet
0 |  | RES | Carbon 1/6W, 5%, 150K | Yageo | CFR-12JB-150K | Digikey | 150KEBK-ND | $0.02 | $0.00 | 0.125Wresistor | Cabinet
0 |  | RES | Carbon 1/6W, 5%, 180K | Yageo | CFR-12JB-180K | Digikey | 180KEBK-ND | $0.02 | $0.00 | 0.125Wresistor | Cabinet
0 |  | RES | Carbon 1/6W, 5%, 200K | Yageo | CFR-12JB-200K | Digikey | 200KEBK-ND | $0.02 | $0.00 | 0.125Wresistor | Cabinet
0 |  | RES | Carbon 1/6W, 5%, 220K | Yageo | CFR-12JB-220K | Digikey | 220KEBK-ND | $0.02 | $0.00 | 0.125Wresistor | Cabinet
0 |  | RES | Carbon 1/6W, 5%, 240K | Yageo | CFR-12JB-240K | Digikey | 240KEBK-ND | $0.02 | $0.00 | 0.125Wresistor | Cabinet
0 |  | RES | Carbon 1/6W, 5%, 270K | Yageo | CFR-12JB-270K | Digikey | 270KEBK-ND | $0.02 | $0.00 | 0.125Wresistor | Cabinet
0 |  | RES | Carbon 1/6W, 5%, 330K | Yageo | CFR-12JB-330K | Digikey | 330KEBK-ND | $0.02 | $0.00 | 0.125Wresistor | Cabinet
0 |  | RES | Carbon 1/6W, 5%, 390K | Yageo | CFR-12JB-390K | Digikey | 390KEBK-ND | $0.02 | $0.00 | 0.125Wresistor | Cabinet
0 |  | RES | Carbon 1/6W, 5%, 470K | Yageo | CFR-12JB-470K | Digikey | 470KEBK-ND | $0.02 | $0.00 | 0.125Wresistor | Cabinet
0 |  | RES | Carbon 1/6W, 5%, 510K | Yageo | CFR-12JB-510K | Digikey | 510KEBK-ND | $0.02 | $0.00 | 0.125Wresistor | Cabinet
0 |  | RES | Carbon 1/6W, 5%, 560K | Yageo | CFR-12JB-560K | Digikey | 560KEBK-ND | $0.02 | $0.00 | 0.125Wresistor | Cabinet
0 |  | RES | Carbon 1/6W, 5%, 680K | Yageo | CFR-12JB-680K | Digikey | 680KEBK-ND | $0.02 | $0.00 | 0.125Wresistor | Cabinet
0 |  | RES | Carbon 1/6W, 5%, 820K | Yageo | CFR-12JB-820K | Digikey | 820KEBK-ND | $0.02 | $0.00 | 0.125Wresistor | Cabinet
0 |  | RES | Carbon 1/6W, 5%, 1M | Yageo | CFR-12JB-1M0 | Digikey | 1.0MEBK-ND | $0.02 | $0.00 | 0.125Wresistor | Cabinet
0 |  | RES | Carbon 1/6W, 5%, 10M | Yageo | CFR-12JB-10M | Digikey | 10MEBK-ND | $0.02 | $0.00 | 0.125Wresistor | Cabinet
0 |  | SW | Tactile Switch, surface mount | C&K Components | KSC353JLFG | Mouser | 611-KSC353JLFG | $0.86 | $0.00 | KSC353JLFG | Cabinet
0 |  | SW | B3F tactile push button switch | Omron Electronics | B3F-1052 | Digikey | SW405-ND | $0.17 | $0.00 | B3F-1050 | Cabinet
0 |  | SW | Black Off board momentary push buttom |  |  | AllElectronics | MPB-5 | $0.35 | $0.00 | OffBoardSwitch | Professor
0 |  | SW | Red Off board momentary push buttom |  |  | AllElectronics | MPB-1 | $0.35 | $0.00 | OffBoardSwitch | Professor
0 |  | SW | On/off power switch |  |  |  |  | $0.85 | $0.00 | OffBoardPowerSwitch | Professor
0 |  | TRAN | PN2222 NPN transistor | Fairchild Semiconductor | PN2222 | Digikey | PN2222BU-ND | $0.13 | $0.00 | 2N2222 | Cabinet | be careful to get pins 1 and 3 correct, there are two versions of the chip: 2N2222 and PN2222
0 |  | TRAN | TIP120 Darlington NPN, TO220 | Fairchild | TIP120 | Digikey | TIP120-ND | $0.68 | $0.00 | TIP120 | Cabinet
0 |  | TRAN | TIP125 Darlington PNP, TO220 | Fairchild | TIP125 | Digikey | TIP125TU-ND | $0.67 | $0.00 | TIP125 | Cabinet
0 |  | TRAN | IRF540 MOSFET N-channel, TO220 |  | IRF540 | Digikey | IRF540NPBF-ND | $1.95 | $0.00 | IRF540 | Cabinet

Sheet: SurfaceMountParts
Quantity | REF DES | Type | Description | Manufacturer | Mfg. P/N | Distributor | P/N | Unit cost | Cost | PCB Artist | Where to get it?
0 |  | CAP | 0805 0.22 uF X7R ceramic |  |  |  |  | $0.14 | $0.00 | Ceramic0805 | Little box of surface mount parts
0 |  | CAP | 0805 220 pF C0G ceramic |  |  |  |  | $0.35 | $0.00 | Ceramic0805 | Little box of surface mount parts
0 |  | RES | 0805 1.1k 1% |  |  |  |  | $0.04 | $0.00 | 0.1WresistorSM805 | Little box of surface mount parts
0 |  | RES | 0805 10k 1% |  |  |  |  | $0.04 | $0.00 | 0.1WresistorSM805 | Little box of surface mount parts
0 |  | RES | 0805 20k 1% |  |  |  |  | $0.04 | $0.00 | 0.1WresistorSM805 | Little box of surface mount parts
0 |  | RES | 0805 25.5k 1% |  |  |  |  | $0.04 | $0.00 | 0.1WresistorSM805 | Little box of surface mount parts
0 |  | RES | 0805 100k 1% |  |  |  |  | $0.04 | $0.00 | 0.1WresistorSM805 | Little box of surface mount parts

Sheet: BOM
Source: | C:\Keil_v5\ValvanoWareTM4C123v5\ece-445l-lab-7-8-11-sp24-ps33536-hjs2235-shp695-wtc534\hw\baseline_project\baseline_project.kicad_sch
Date: | 2024-03-28 17:34
Tool: | Eeschema 7.0.10
Generator: | C:\Program Files\KiCad\7.0\bin\scripting\plugins/bom_csv_grouped_by_value.py
Component Count: | 50
Collated Components:
Item | Qty | Reference(s) | Value | LibPart | Footprint | Datasheet | DNP | Cost | Distributor | Manufacturer | P/N
1 | 1 | C1 | 1uF | Device:C | ECE445L:C_Axial_200mil | ~ | Checkout | $0
2 | 7 | C2, C6, C7, C8, C9, C10, C11 | 0.1uF | ECE445L:C | ECE445L:C_Axial_200mil | ~ | Checkout | $0
3 | 3 | C3, C4, C5 | 4.7uF | Device:C | ECE445L:C_Axial_200mil | ~ | Checkout | $0
4 | 2 | C101, C102 | 100nF | Device:C_Small | ECE445L:C_Axial_200mil | ~ | Checkout | $0
5 | 2 | C103, C104 | 4.7uF | Device:C_Polarized_Small_US | ECE445L:CP_Radial_Tantal200mil | ~ | Checkout | $0
6 | 4 | H1, H2, H3, H4 | ~ | ECE445L:MountingHole | ECE445L:MountingHole_4_40 |  | Checkout | $0
7 | 1 | IC1 | LM4041CILPR | ti_LM4041CILPR:LM4041CILPR | ECE445L:ti_LM4041CILPR | https://www.ti.com/general/docs/suppproductinfo.tsp?distId=26&gotoUrl=https://www.ti.com/lit/gpn/lm4041a12 | Checkout | $0 | Mouser | Texas Instruments | LM4041CILPR
8 | 1 | J1 | AudioJack | ECE445L:HeadphoneJack | ECE445L:Jack_3.5mm_CUI_SJ1-3523N_Horizontal | ~ | Checkout | $0
9 | 1 | J2 | Header_4 | ECE445L:Header_4 | ECE445L:PinHeader_1x04_P2.54mm_Vertical | ~ | Checkout | $0
10 | 1 | JP1 | Jumper_3_Open | ECE445L:Jumper_3_Open | ECE445L:PinHeader_1x03_P2.54mm_Vertical | ~ | Checkout | $0
11 | 1 | R1 | 20k | Device:R | Resistor_THT:R_Axial_DIN0207_L6.3mm_D2.5mm_P10.16mm_Horizontal | ~ | Checkout | $0
12 | 3 | R2, R5, R12 | 10k | Device:R | Resistor_THT:R_Axial_DIN0207_L6.3mm_D2.5mm_P10.16mm_Horizontal | ~ | Checkout | $0
13 | 1 | R3 | 2k | Device:R | Resistor_THT:R_Axial_DIN0207_L6.3mm_D2.5mm_P10.16mm_Horizontal | ~ | Checkout | $0
14 | 1 | R4 | 47k | Device:R | Resistor_THT:R_Axial_DIN0207_L6.3mm_D2.5mm_P10.16mm_Horizontal | ~ | Checkout | $0
15 | 1 | R11 | 10k | ECE445L:Potentiometer | ECE445L:Potentiometer |  | Checkout | $0
16 | 1 | R101 | 10k | Device:R_Small | Resistor_THT:R_Axial_DIN0207_L6.3mm_D2.5mm_P10.16mm_Horizontal | ~ | Checkout | $0
17 | 1 | SW1 | RESET | Switch:SW_Push | Button_Switch_THT:SW_PUSH_6mm | ~ | Checkout | $0
18 | 1 | SW101 | UP | Switch:SW_Push | Button_Switch_THT:SW_PUSH_6mm | ~ | Checkout | $0
19 | 1 | SW102 | DOWN | Switch:SW_Push | Button_Switch_THT:SW_PUSH_6mm | ~ | Checkout | $0
20 | 1 | SW103 | LEFT | Switch:SW_Push | Button_Switch_THT:SW_PUSH_6mm | ~ | Checkout | $0
21 | 1 | SW104 | RIGHT | Switch:SW_Push | Button_Switch_THT:SW_PUSH_6mm | ~ | Checkout | $0
22 | 1 | SW105 | MODE | Switch:SW_Push | Button_Switch_THT:SW_PUSH_6mm | ~ | Checkout | $0
23 | 7 | TP1, TP2, TP3, TP4, TP5, TP6, TP7 | TP | ECE445L:Testpoint | ECE445L:Testpoint_1x02_P2.54mm | ~ | Checkout | $0
24 | 1 | U1 | TLV5616CP | ti_TLV5616CP:TLV5616CP | ECE445L:ul_TLV5616CP | TLV5616CP | Checkout | $0
25 | 1 | U3 | LM2937xMP | Regulator_Linear:LM2937xMP | ECE445L:LM2937 | http://www.ti.com/lit/ds/symlink/lm2937.pdf | Checkout | $0
26 | 1 | U4 | MCP34119P | ECE445L:MCP34119P | ECE445L:DIP-8_W7.62mm_LongPads | https://users.ece.utexas.edu/~valvano/Datasheets/MC34119.pdf | Checkout | $0 | N/A | Motorola | MC34119P
27 | 1 | U101 | EK-TM4C123GXL | ti_EKTM4C123GXL:EK-TM4C123GXL | ECE445L:ti_EKTM4C123GXL | https://www.ti.com/lit/ds/symlink/tm4c123gh6pm.pdf?ts=1693244962384 | Checkout | $0 | Mouser | Texas Instruments | EK-TM4C123GXL
28 | 1 | U102 | ESP8266-01/ESP-01 | ai_thinker_ESP8266_01:ESP8266-01/ESP-01 | ECE445L:ai_thinker_ESP8266_01 | https://nurdspace.nl/ESP8266 | Checkout | $0 | Mouser | SparkFun | WRL-17146
29 | 1 | U103 | ILI9341 | Hosyond | ECE445L:adafruit_st7735r |  | Amazon | $15 | Mouser | Adafruit | 358
 | 1 | SD Card | SD Card |  |  |  | Amazon | $6

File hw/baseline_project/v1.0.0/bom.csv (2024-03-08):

Designator | Footprint | Quantity | Value | LCSC Part #
C101, C102 | C_Axial_L5.1mm_D3.1mm_P15.00mm_Horizontal | 2 | 100nF
C103, C104 | CP_Axial_L10.0mm_D4.5mm_P15.00mm_Horizontal | 2 | 4.7uF
D101 | D_5W_P12.70mm_Horizontal | 1 | 1V0
J101 | Samtec_HPM-02-01-x-S_Straight_1x02_Pitch5.08mm | 1 | EXT_3V3
LS101 | PinHeader_1x02_P2.54mm_Vertical | 1 | Speaker
Q101 | vishay_IRLD024PBF | 1 | IRLD024PBF
R101 | R_Axial_DIN0411_L9.9mm_D3.6mm_P15.24mm_Horizontal | 1 | 10k
SW101 | SW_PUSH_6mm | 1 | UP
SW102 | SW_PUSH_6mm | 1 | DOWN
SW103 | SW_PUSH_6mm | 1 | LEFT
SW104 | SW_PUSH_6mm | 1 | RIGHT
SW105 | SW_PUSH_6mm | 1 | MODE
U101 | ti_EKTM4C123GXL | 1 | EK-TM4C123GXL
U102 | ai_thinker_ESP8266_01 | 1 | ESP8266-01/ESP-01
U103 | adafruit_st7735r | 1 | Adafruit ST7735R

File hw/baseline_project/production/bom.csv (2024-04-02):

Designator | Footprint | Quantity | Value | LCSC Part #
C1 | C_Axial_200mil | 1 | 1uF
C10, C11, C2, C6, C7, C8, C9 | C_Axial_200mil | 7 | 0.1uF
C101, C12 | C_Axial_200mil | 2 | 100nF
C103, C13 | CP_Radial_Tantal200mil | 2 | 4.7uF
C3, C4, C5 | C_Axial_200mil | 3 | 4.7uF
H1, H2, H3, H4 | MountingHole_4_40 | 4 | ~
IC1 | ti_LM4041CILPR | 1 | LM4041CILPR
J1 | Jack_3.5mm_CUI_SJ1-3523N_Horizontal | 1 | AudioJack
J2 | PinHeader_1x04_P2.54mm_Vertical | 1 | Header_4
R1 | R_Axial_DIN0207_L6.3mm_D2.5mm_P10.16mm_Horizontal | 1 | 20k
R101, R12, R2, R5 | R_Axial_DIN0207_L6.3mm_D2.5mm_P10.16mm_Horizontal | 4 | 10k
R11 | Potentiometer | 1 | 10k
R3 | R_Axial_DIN0207_L6.3mm_D2.5mm_P10.16mm_Horizontal | 1 | 2k
R4 | R_Axial_DIN0207_L6.3mm_D2.5mm_P10.16mm_Horizontal | 1 | 47k
SW1 | SW_PUSH_6mm | 1 | RESET
SW101 | SW_PUSH_6mm | 1 | UP
SW102 | SW_PUSH_6mm | 1 | DOWN
SW103 | SW_PUSH_6mm | 1 | LEFT
SW104 | SW_PUSH_6mm | 1 | RIGHT
SW105 | SW_PUSH_6mm | 1 | MODE
TP2, TP3, TP4, TP5, TP6, TP7 | Testpoint_1x02_P2.54mm | 6 | TP
U1 | ul_TLV5616CP | 1 | TLV5616CP
U101 | ti_EKTM4C123GXL | 1 | EK-TM4C123GXL
U102 | ai_thinker_ESP8266_01 | 1 | ESP8266-01/ESP-01
U2 | TFT-320x240 | 1 | ILI_Display
U3 | LM2937 | 1 | LM2937xMP
U4 | DIP-8_W7.62mm_LongPads | 1 | MCP34119P

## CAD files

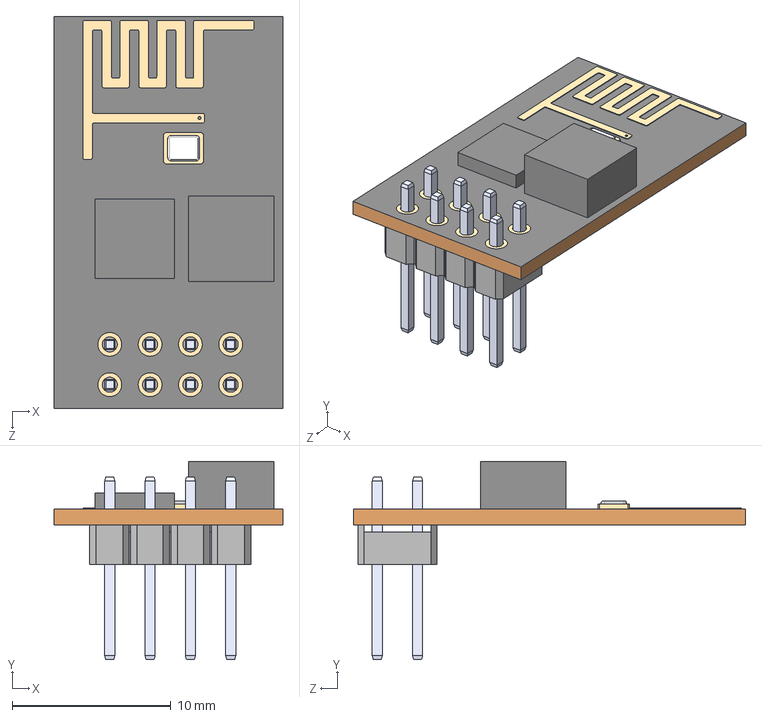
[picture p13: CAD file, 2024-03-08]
hw/baseline_project/models/ai_thinker_ESP8266-01.step
14.4 x 12.5 x 24.7 mm

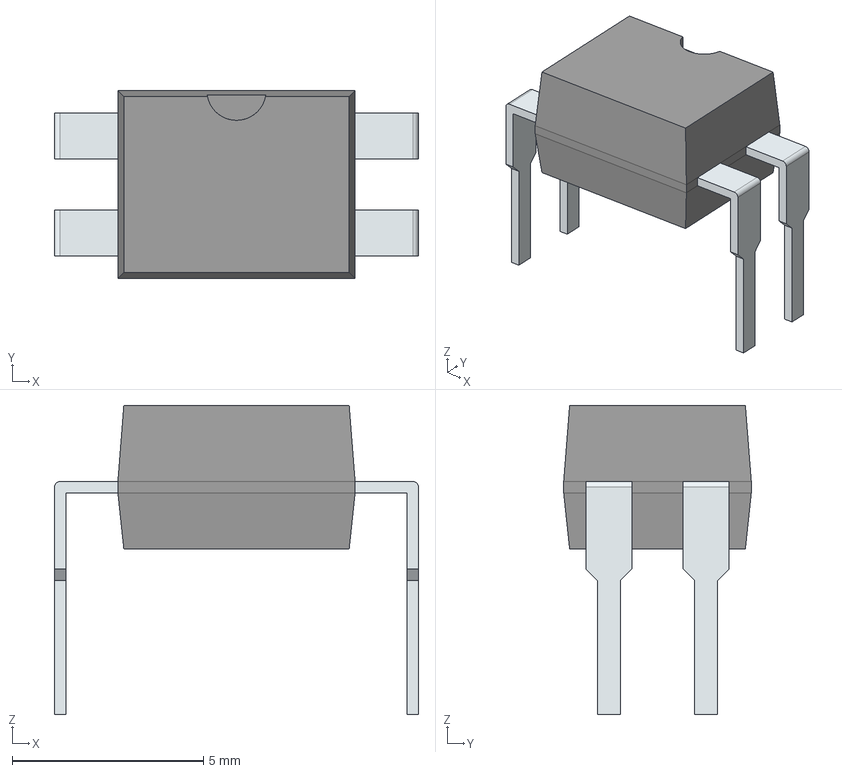
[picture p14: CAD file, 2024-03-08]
hw/baseline_project/models/vishay_IRLD024PBF.stp
9.51 x 4.90 x 8.07 mm
PinsArrayLR

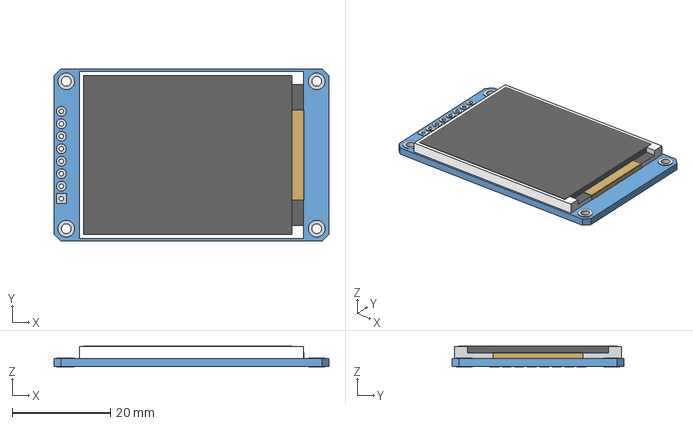
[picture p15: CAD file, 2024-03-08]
hw/baseline_project/models/adafruit_st7735r.stp
56.0 x 35.0 x 4.25 mm

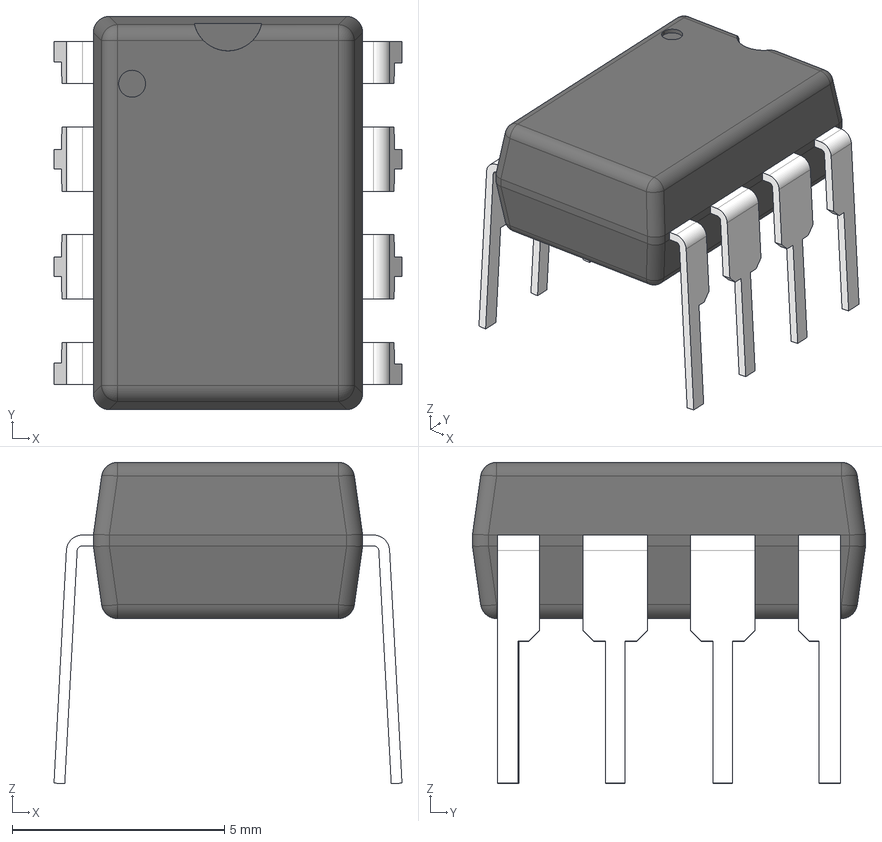
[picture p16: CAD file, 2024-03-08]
hw/baseline_project/models/ti_TLV5618AIP.stp
8.20 x 9.27 x 7.58 mm
BODY_P0008A
LEAD_P0008A x 4
LD_LHALF_P0008A x 2
LD_RHALF_P0008A x 2

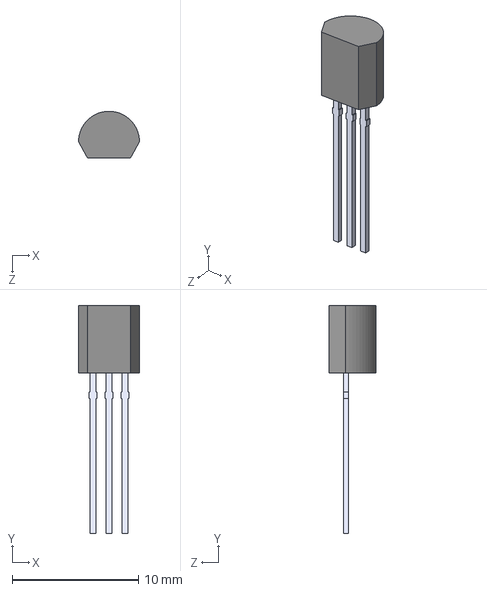
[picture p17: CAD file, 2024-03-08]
hw/baseline_project/models/ti_LM4041CILPR.step
4.82 x 18.0 x 3.68 mm

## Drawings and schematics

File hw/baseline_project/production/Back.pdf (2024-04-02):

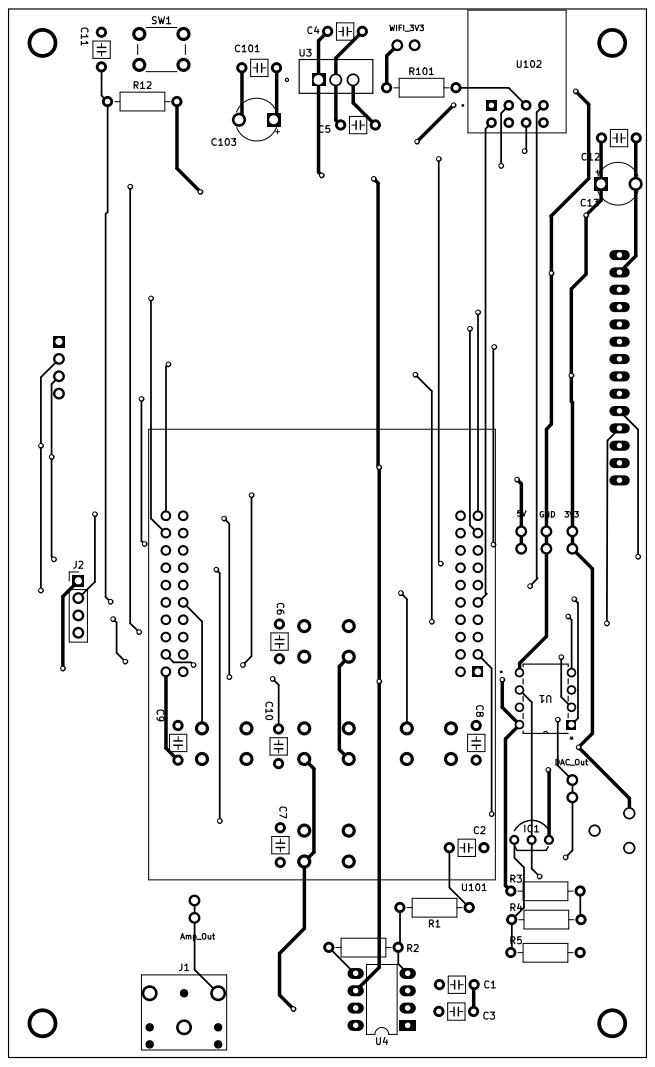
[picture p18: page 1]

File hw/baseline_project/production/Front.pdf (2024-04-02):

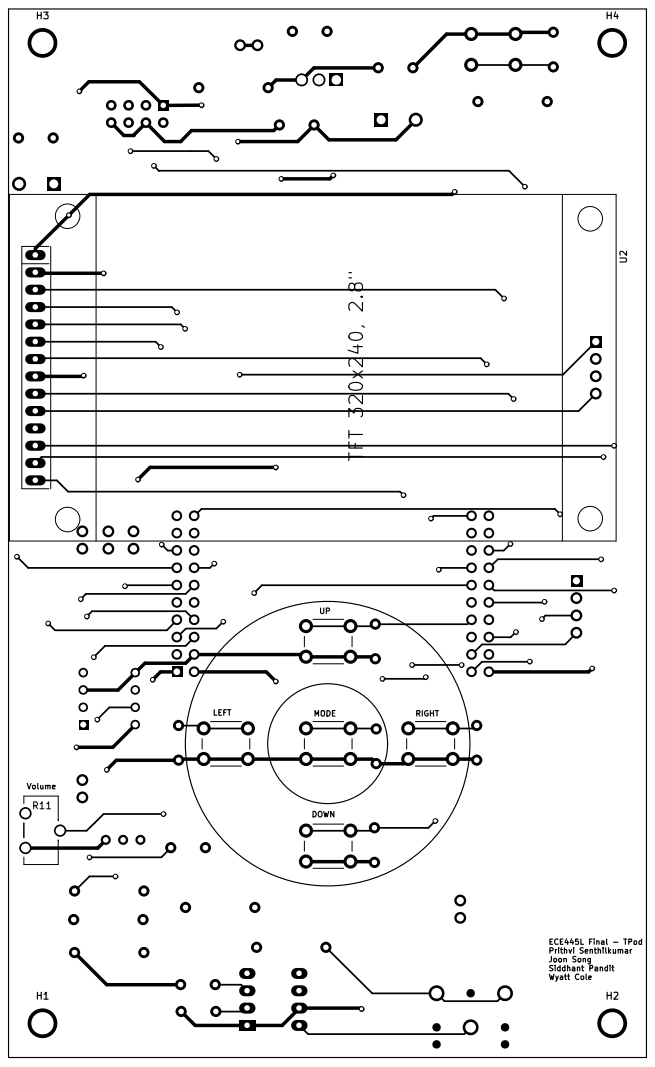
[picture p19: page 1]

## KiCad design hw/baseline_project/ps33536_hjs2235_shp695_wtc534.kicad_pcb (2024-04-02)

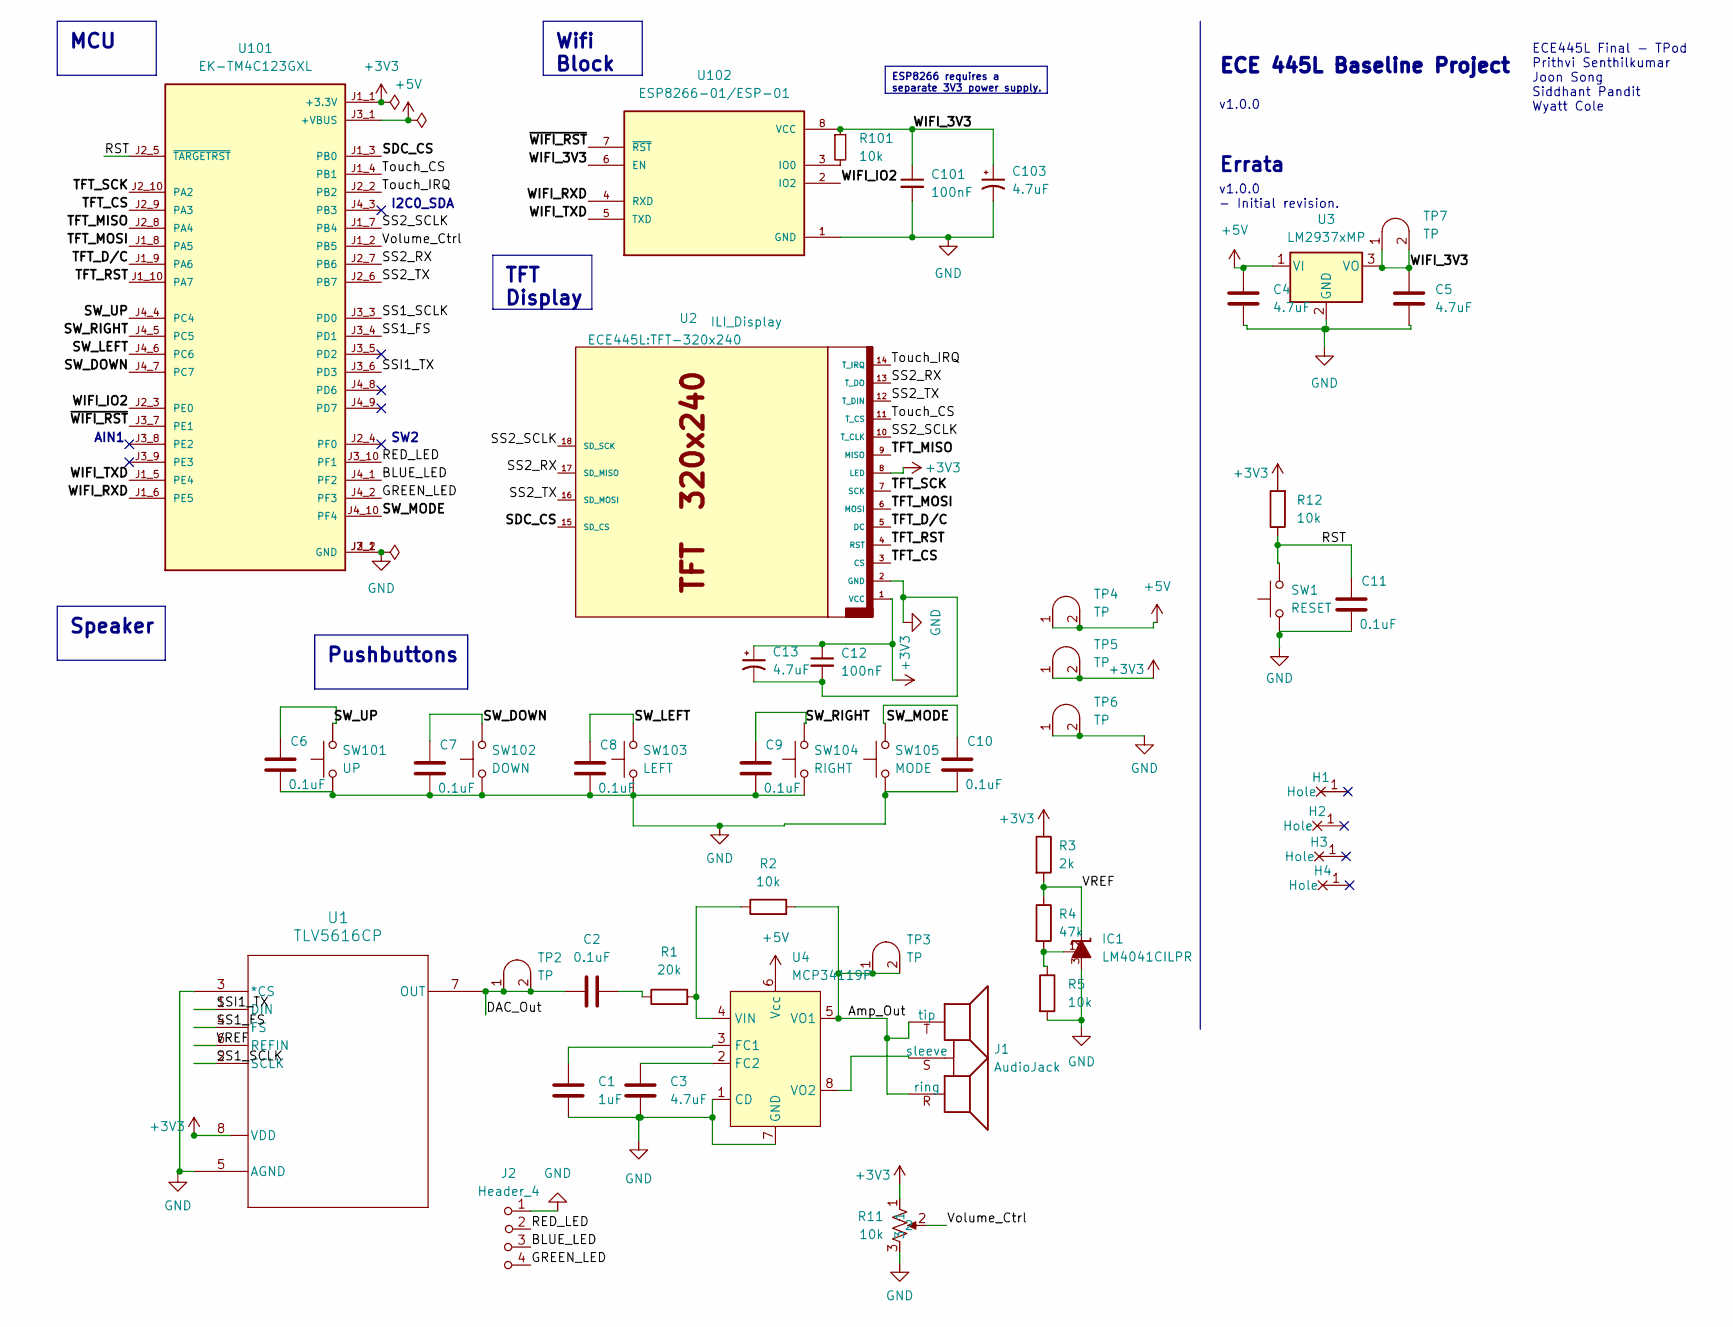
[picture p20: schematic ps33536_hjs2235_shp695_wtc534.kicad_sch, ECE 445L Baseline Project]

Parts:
C1: 1uF; C_Axial_200mil
C2, C6, C7, C8, C9, C10, C11: 0.1uF; C_Axial_200mil
C3, C4, C5: 4.7uF; C_Axial_200mil
C12, C101: 100nF; C_Axial_200mil
C13, C103: 4.7uF; CP_Radial_Tantal200mil
H1, H2, H3, H4: MountingHole_4_40
IC1: LM4041CILPR; ti_LM4041CILPR
J1: AudioJack; Jack_3.5mm_CUI_SJ1-3523N_Horizontal
J2: Header_4; PinHeader_1x04_P2.54mm_Vertical
R1: 20k; R_Axial_DIN0207_L6.3mm_D2.5mm_P10.16mm_Horizontal
R2, R5, R12, R101: 10k; R_Axial_DIN0207_L6.3mm_D2.5mm_P10.16mm_Horizontal
R3: 2k; R_Axial_DIN0207_L6.3mm_D2.5mm_P10.16mm_Horizontal
R4: 47k; R_Axial_DIN0207_L6.3mm_D2.5mm_P10.16mm_Horizontal
R11: 10k; Potentiometer
SW1: RESET; SW_PUSH_6mm
SW101: UP; SW_PUSH_6mm
SW102: DOWN; SW_PUSH_6mm
SW103: LEFT; SW_PUSH_6mm
SW104: RIGHT; SW_PUSH_6mm
SW105: MODE; SW_PUSH_6mm
TP2, TP3, TP4, TP5, TP6, TP7: TP; Testpoint_1x02_P2.54mm
U1: TLV5616CP; ul_TLV5616CP
U2: ILI_Display; TFT-320x240
U3: LM2937xMP; LM2937
U4: MCP34119P; DIP-8_W7.62mm_LongPads
U101: EK-TM4C123GXL; ti_EKTM4C123GXL
U102: ESP8266-01/ESP-01; ai_thinker_ESP8266_01

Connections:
+3V3: C12.1, C13.1, R3.1, R11.1, R12.2, TP5.1 (A), TP5.2 (B), U1.8 (VDD), U2.1 (VCC), U2.8 (LED), U101.J1_1 (+3.3V)
+5V: C4.1, TP4.1 (A), TP4.2 (B), U3.1 (VI), U4.6 (Vcc), U101.J3_1 (+VBUS)
/Amp_Out: J1.R (ring), J1.T (tip), R2.2, TP3.1 (A), TP3.2 (B), U4.5 (VO1)
/BLUE_LED: J2.3 (C), U101.J4_1 (PF2)
/DAC_Out: C2.2, TP2.1 (A), TP2.2 (B), U1.7 (OUT)
/GREEN_LED: J2.4 (C), U101.J4_2 (PF3)
/RED_LED: J2.2 (B), U101.J3_10 (PF1)
/RST: C11.1, R12.1, SW1.2, U101.J2_5 (~TARGETRST)
/SDC_CS: U2.15 (SD_CS), U101.J1_3 (PB0)
/SS1_FS: U1.4 (FS), U101.J3_4 (PD1)
/SS1_SCLK: U1.2 (SCLK), U101.J3_3 (PD0)
/SS2_RX: U2.13 (T_DO), U2.17 (SD_MISO), U101.J2_7 (PB6)
/SS2_SCLK: U2.10 (T_CLK), U2.18 (SD_SCK), U101.J1_7 (PB4)
/SS2_TX: U2.12 (T_DIN), U2.16 (SD_MOSI), U101.J2_6 (PB7)
/SSI1_TX: U1.1 (DIN), U101.J3_6 (PD3)
/SW_DOWN: C7.1, SW102.2, U101.J4_7 (PC7)
/SW_LEFT: C8.1, SW103.2, U101.J4_6 (PC6)
/SW_MODE: C10.1, SW105.2, U101.J4_10 (PF4)
/SW_RIGHT: C9.1, SW104.2, U101.J4_5 (PC5)
/SW_UP: C6.1, SW101.2, U101.J4_4 (PC4)
/TFT_CS: U2.3 (CS), U101.J2_9 (PA3)
/TFT_D/C: U2.5 (DC), U101.J1_9 (PA6)
/TFT_MISO: U2.9 (MISO), U101.J2_8 (PA4)
/TFT_MOSI: U2.6 (MOSI), U101.J1_8 (PA5)
/TFT_RST: U2.4 (RST), U101.J1_10 (PA7)
/TFT_SCK: U2.7 (SCK), U101.J2_10 (PA2)
/Touch_CS: U2.11 (T_CS), U101.J1_4 (PB1)
/Touch_IRQ: U2.14 (T_IRQ), U101.J2_2 (PB2)
/VREF: IC1.2, R3.2, R4.1, U1.6 (REFIN)
/Volume_Ctrl: R11.2, U101.J1_2 (PB5)
/WIFI_3V3: C5.1, C101.1, C103.1, R101.1, TP7.1 (A), TP7.2 (B), U3.3 (VO), U102.6 (EN), U102.8 (VCC)
/WIFI_IO2: U101.J2_3 (PE0), U102.2 (IO2)
/WIFI_RXD: U101.J1_6 (PE5), U102.4 (RXD)
/WIFI_TXD: U101.J1_5 (PE4), U102.5 (TXD)
/~WIFI_RST: U101.J3_7 (PE1), U102.7 (~RST)
GND: C1.2, C3.2, C4.2, C5.2, C6.2, C7.2, C8.2, C9.2, C10.2, C11.2, C12.2, C13.2, C101.2, C103.2, IC1.3, J2.1 (A), R5.2, R11.3, SW1.1, SW101.1, SW102.1, SW103.1, SW104.1, SW105.1, TP6.1 (A), TP6.2 (B), U1.3 (*CS), U1.5 (AGND), U2.2 (GND), U3.2 (GND), U4.1 (CD), U4.7 (GND), U101.J2_1 (GND), U101.J3_2 (GND), U102.1 (GND)
unnamed: C2.1, R1.1
unnamed: IC1.1, R4.2, R5.1
unnamed: J1.S (sleeve), U4.8 (VO2)
unnamed: C1.1, U4.3 (FC1)
unnamed: C3.1, U4.2 (FC2)
unnamed: R1.2, R2.1, U4.4 (VIN)
unnamed: R101.2, U102.3 (IO0)

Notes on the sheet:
MCU
ESP8266 requires a separate 3V3 power supply.
Speaker
Pushbuttons
TFT Display
Wifi Block
v1.0.0 - Initial revision.
AIN1
ECE 445L Baseline Project
v1.0.0
Errata
ECE445L Final - TPod Prithvi Senthilkumar Joon Song Siddhant Pandit Wyatt Cole
I2C0_SDA
SW2

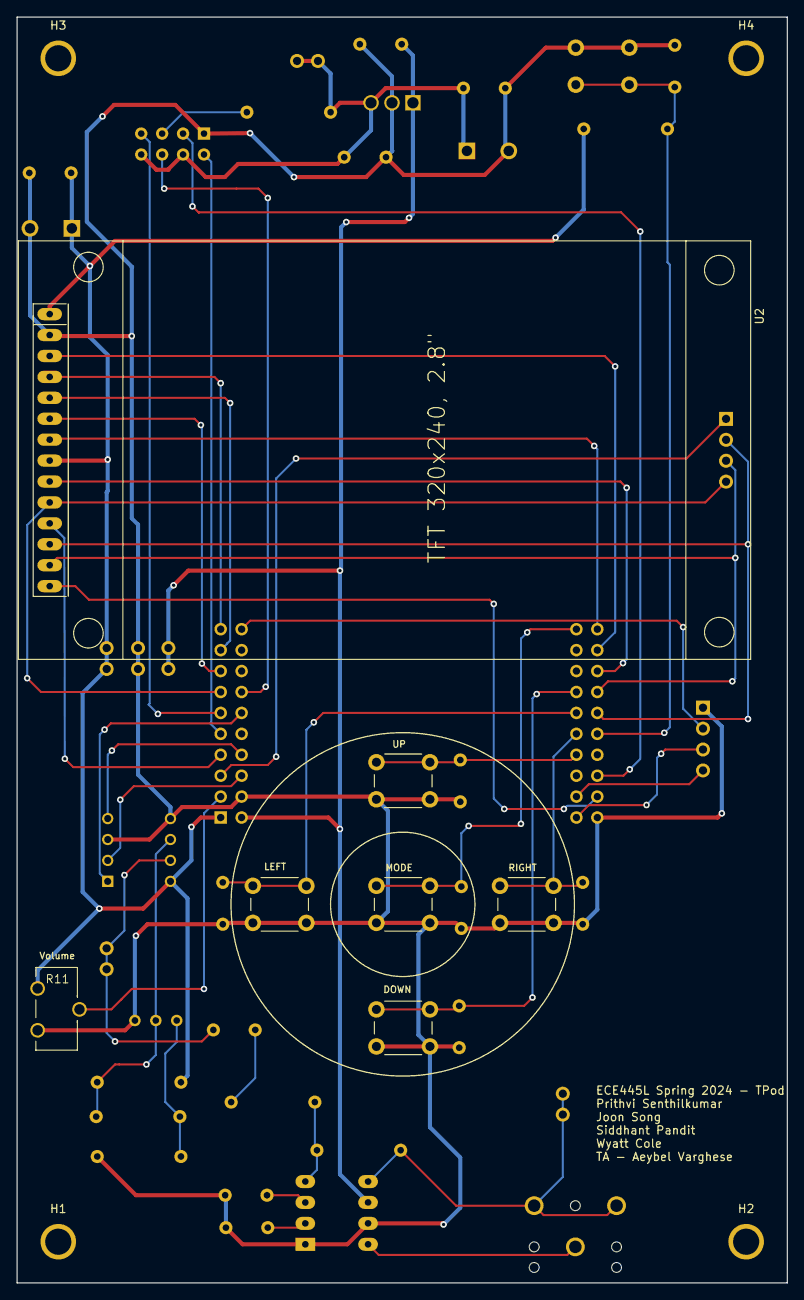
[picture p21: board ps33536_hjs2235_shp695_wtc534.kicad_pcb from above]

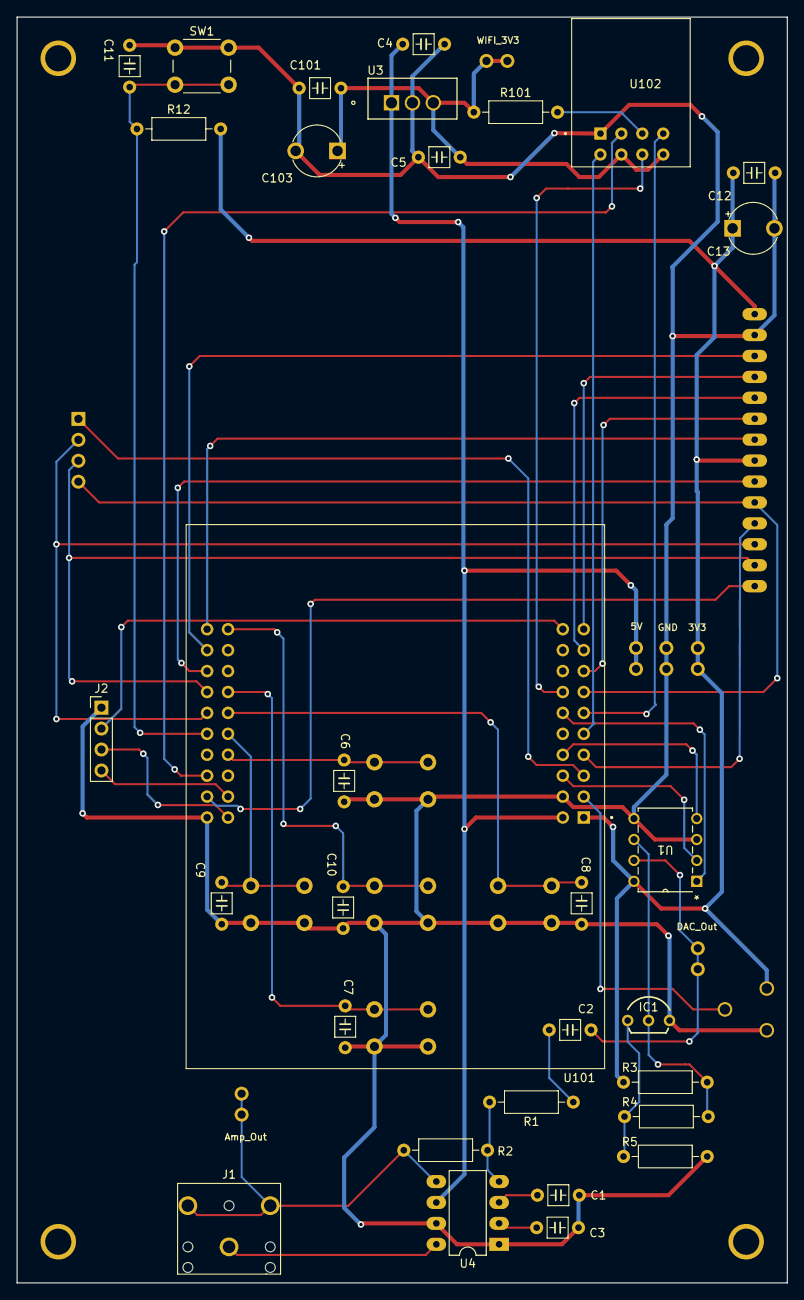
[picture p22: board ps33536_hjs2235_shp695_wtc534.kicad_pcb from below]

Board: 2 copper layers, 93.5 x 153.7 mm, 48 parts (37 on the bottom side), 43 nets.

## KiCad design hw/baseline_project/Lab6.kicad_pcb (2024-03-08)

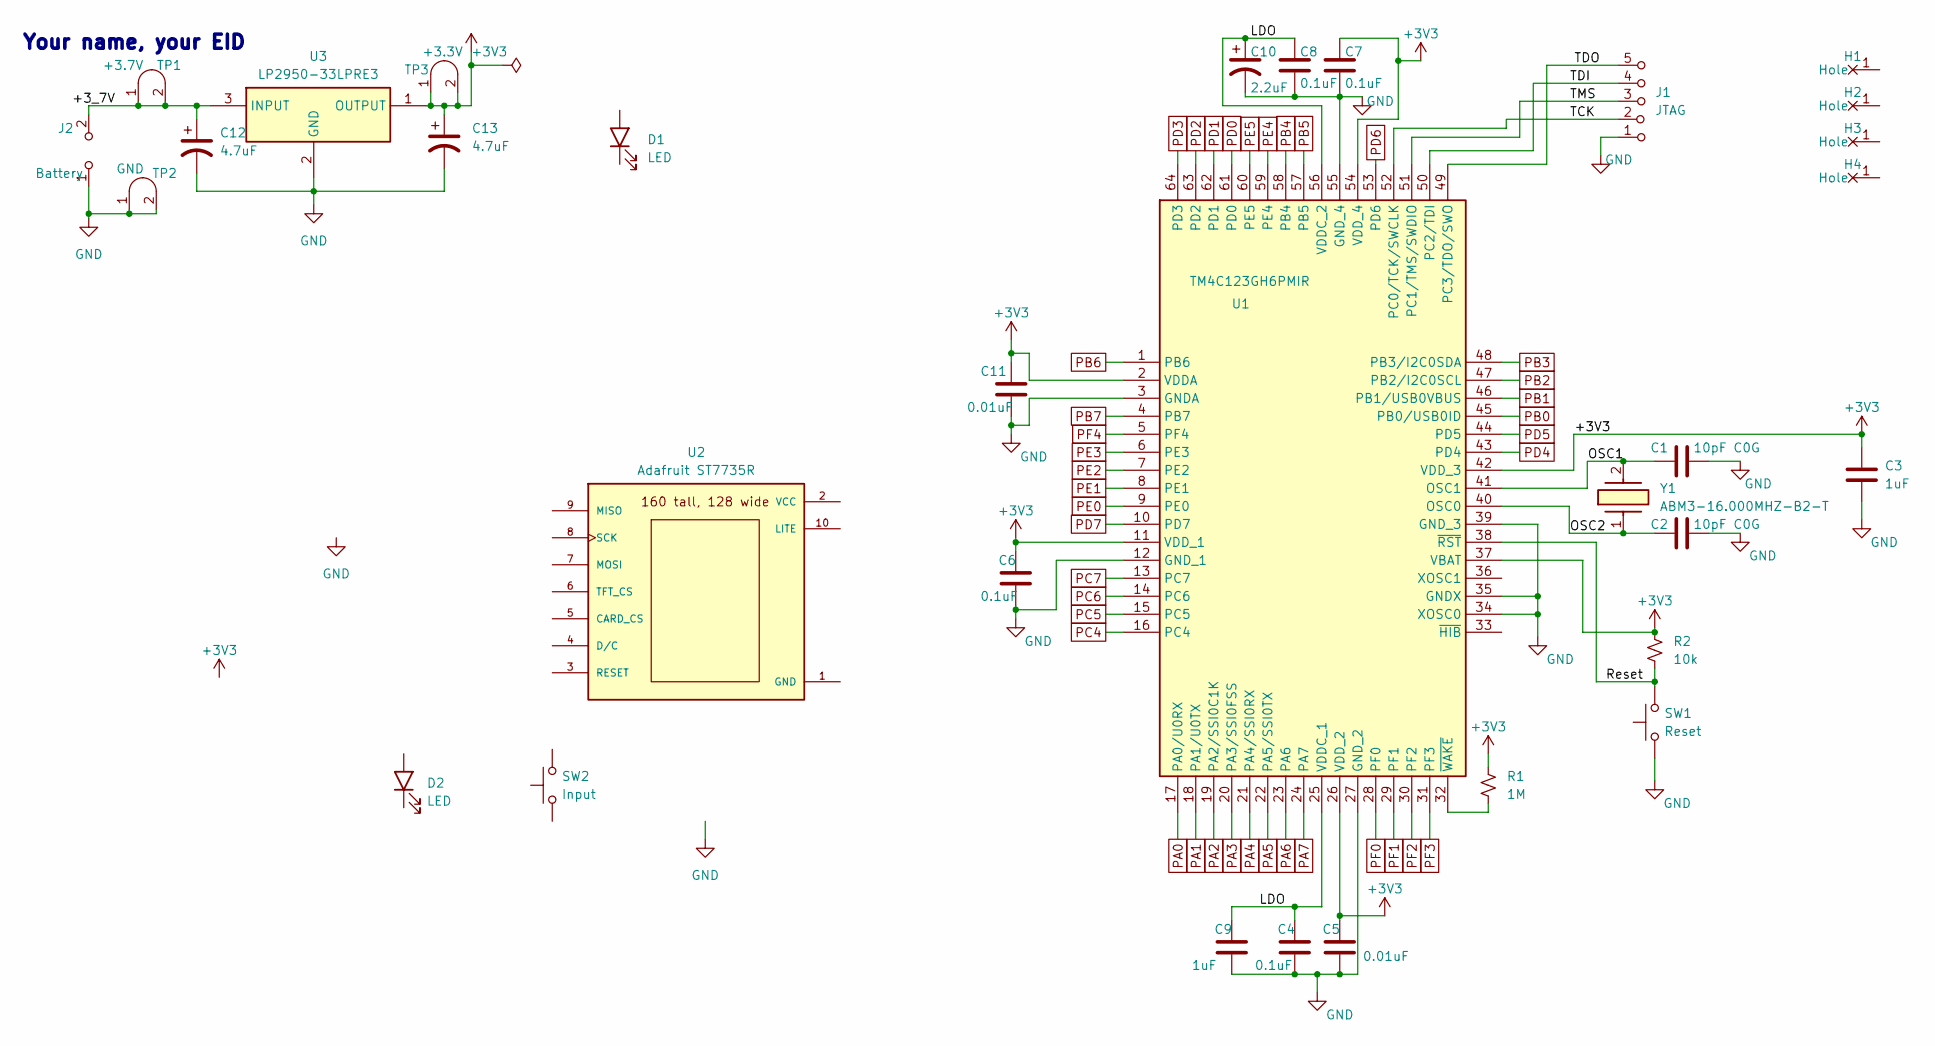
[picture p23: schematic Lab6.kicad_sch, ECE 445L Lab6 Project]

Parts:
C1, C2: 10pF C0G; C_Axial_200mil
C3, C9: 1uF; C_Axial_200mil
C4, C6, C7, C8: 0.1uF; C_Axial_200mil
C5, C11: 0.01uF; C_Axial_200mil
C10: 2.2uF; CP_Radial_Tantal200mil
C12, C13: 4.7uF; CP_Radial_Tantal200mil
D1, D2: LED; LED_D5.0mm
H1, H2, H3, H4: MountingHole_4_40
J1: JTAG; PinHeader_1x05_P2.54mm_Vertical
J2: Battery; PinHeader_1x02_P2.54mm_Vertical
R1: 1M; R_Axial_DIN0204_L3.6mm_D1.6mm_P7.62mm_Horizontal
R2: 10k; R_Axial_DIN0204_L3.6mm_D1.6mm_P7.62mm_Horizontal
SW1: Reset; SW_PUSH_6mm
SW2: Input; SW_PUSH_6mm
TP1: +3.7V; Testpoint_1x02_P2.54mm
TP2: GND; Testpoint_1x02_P2.54mm
TP3: +3.3V; Testpoint_1x02_P2.54mm
U1: TM4C123GH6PMIR; QFP50P1200X1200X160-64N; Mouser Part Number 595-TM4C123GH6PMIR
U2: Adafruit ST7735R; adafruit_st7735r2
U3: LP2950-33LPRE3; TL431CLPM; Mouser Part Number 595-LP2950-33LPRE3
Y1: ABM3-16.000MHZ-B2-T; ABM3; Mouser Part Number 815-ABM3-16-B2-T

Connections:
+3V3: C3.1, C5.1, C6.1, C7.1, C11.1, C13.1, R1.1, R2.1, TP3.1 (A), TP3.2 (B), U1.2 (VDDA), U1.11 (VDD_1), U1.26 (VDD_2), U1.37 (VBAT), U1.42 (VDD_3), U1.54 (VDD_4), U3.1 (OUTPUT)
/+3_7V: C12.1, J2.2 (B), TP1.1 (A), TP1.2 (B), U3.3 (INPUT)
/LDO: C4.1, C8.1, C9.1, C10.1, U1.25 (VDDC_1), U1.56 (VDDC_2)
/OSC1: C1.1, U1.41 (OSC1), Y1.2
/OSC2: C2.1, U1.40 (OSC0), Y1.1
/Reset: R2.2, SW1.2, U1.38 (~RST)
/TCK: J1.2 (B), U1.52 (PC0/TCK/SWCLK)
/TDI: J1.4 (C), U1.50 (PC2/TDI)
/TDO: J1.5 (C), U1.49 (PC3/TDO/SWO)
/TMS: J1.3 (C), U1.51 (PC1/TMS/SWDIO)
GND: C1.2, C2.2, C3.2, C4.2, C5.2, C6.2, C7.2, C8.2, C9.2, C10.2, C11.2, C12.2, C13.2, J1.1 (A), J2.1 (A), SW1.1, TP2.1 (A), TP2.2 (B), U1.3 (GNDA), U1.12 (GND_1), U1.27 (GND_2), U1.34 (XOSC0), U1.35 (GNDX), U1.39 (GND_3), U1.55 (GND_4), U3.2 (GND)
unnamed: R1.2, U1.32 (~WAKE)
PA0: U1.17 (PA0/U0RX)
PA1: U1.18 (PA1/U0TX)
PA2: U1.19 (PA2/SSI0C1K)
PA3: U1.20 (PA3/SSI0FSS)
PA4: U1.21 (PA4/SSI0RX)
PA5: U1.22 (PA5/SSI0TX)
PA6: U1.23 (PA6)
PA7: U1.24 (PA7)
PB0: U1.45 (PB0/USB0ID)
PB1: U1.46 (PB1/USB0VBUS)
PB2: U1.47 (PB2/I2C0SCL)
PB3: U1.48 (PB3/I2C0SDA)
PB4: U1.58 (PB4)
PB5: U1.57 (PB5)
PB6: U1.1 (PB6)
PB7: U1.4 (PB7)
PC4: U1.16 (PC4)
PC5: U1.15 (PC5)
PC6: U1.14 (PC6)
PC7: U1.13 (PC7)
PD0: U1.61 (PD0)
PD1: U1.62 (PD1)
PD2: U1.63 (PD2)
PD3: U1.64 (PD3)
PD4: U1.43 (PD4)
PD5: U1.44 (PD5)
PD6: U1.53 (PD6)
PD7: U1.10 (PD7)
PE0: U1.9 (PE0)
PE1: U1.8 (PE1)
PE2: U1.7 (PE2)
PE3: U1.6 (PE3)
PE4: U1.59 (PE4)
PE5: U1.60 (PE5)
PF0: U1.28 (PF0)
PF1: U1.29 (PF1)
PF2: U1.30 (PF2)
PF3: U1.31 (PF3)
PF4: U1.5 (PF4)

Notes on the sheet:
Your name, your EID

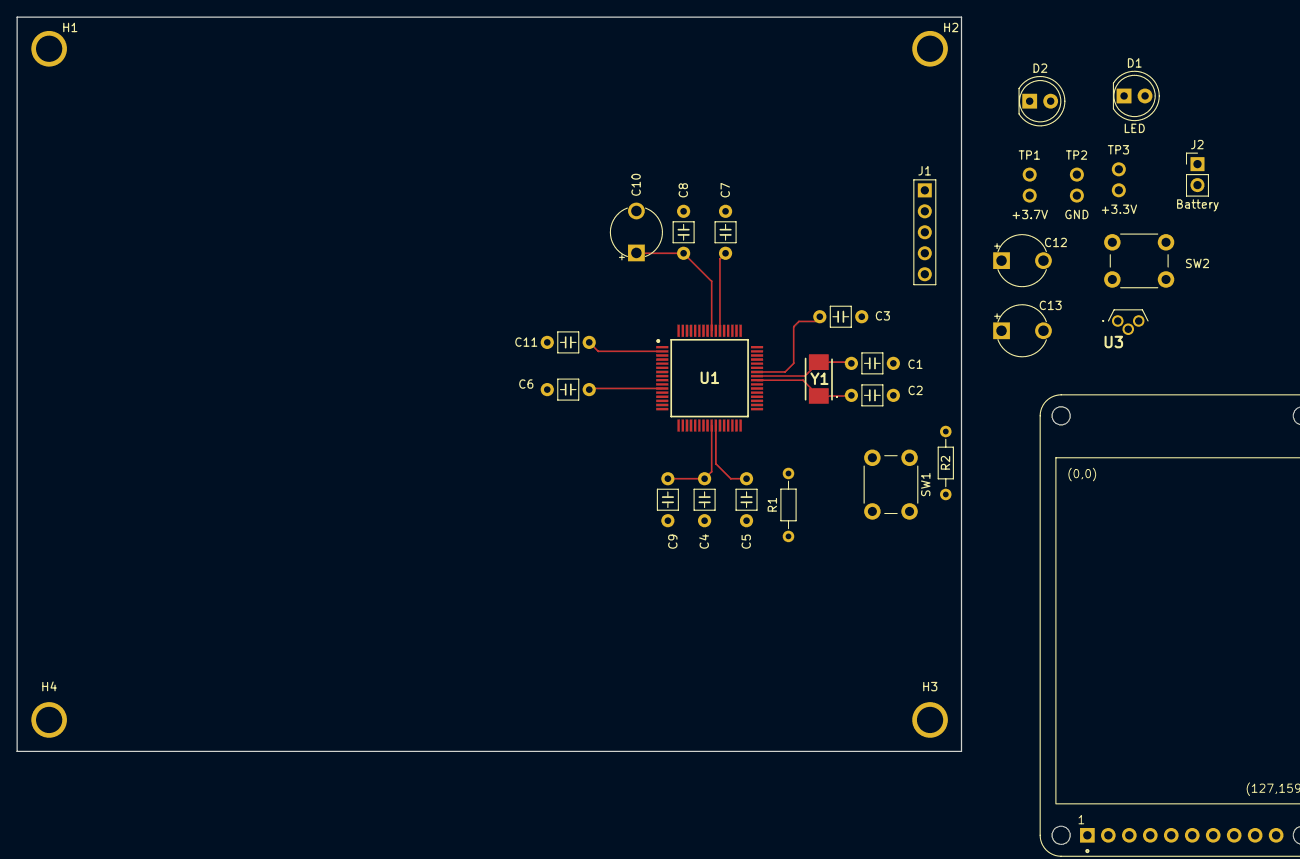
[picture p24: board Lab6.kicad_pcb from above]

Board: 2 copper layers, 114.4 x 88.9 mm, 32 parts (0 on the bottom side), 12 nets.

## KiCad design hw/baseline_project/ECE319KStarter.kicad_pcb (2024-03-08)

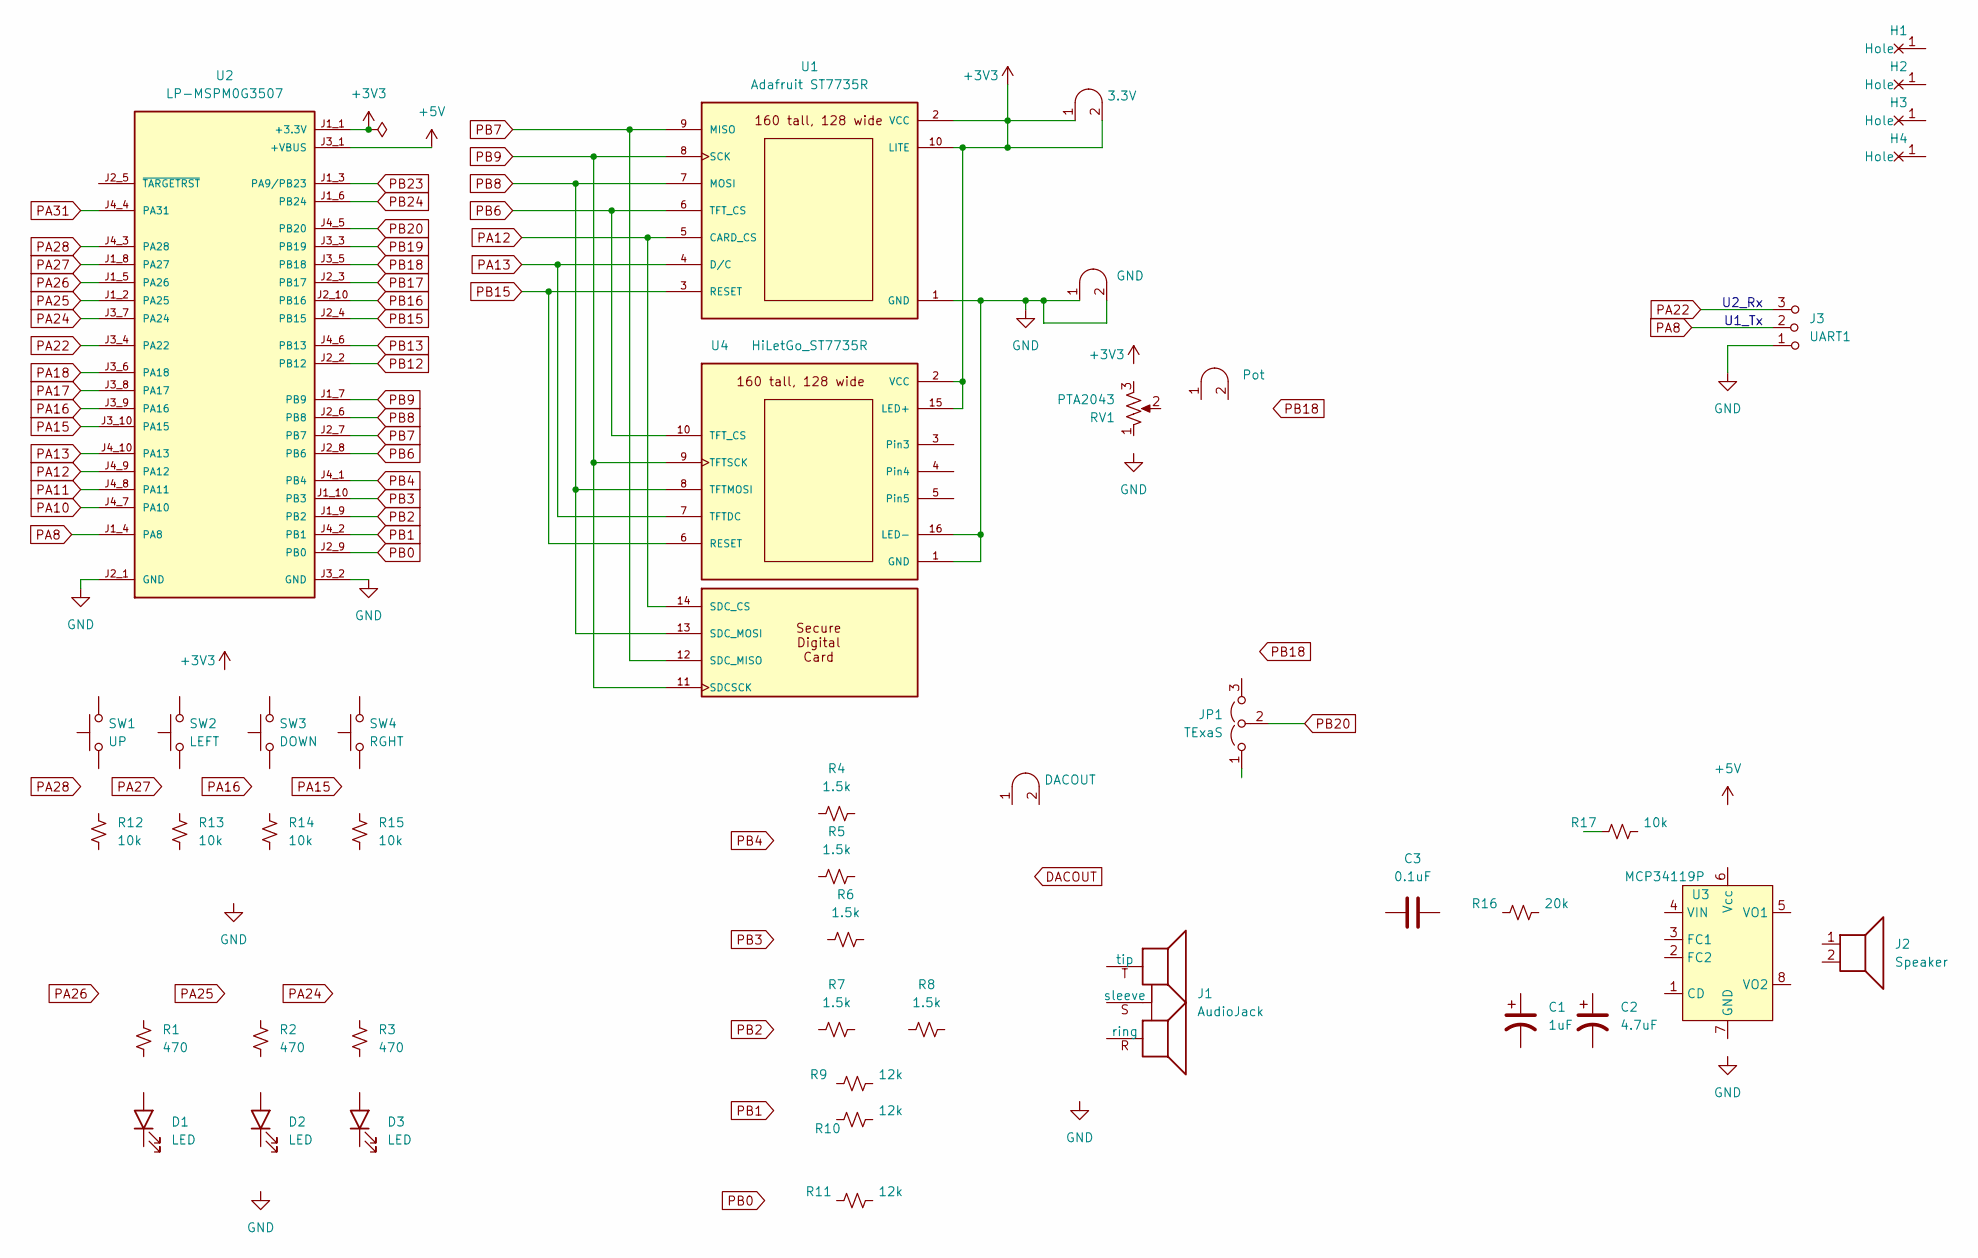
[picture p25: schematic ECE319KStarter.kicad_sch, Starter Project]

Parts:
C1: 1uF; CP_Radial_Tantal200mil
C2: 4.7uF; CP_Radial_Tantal200mil
C3: 0.1uF; C_Axial_200mil
D1, D2, D3: LED; LED_D5.0mm
H1, H2, H3, H4: MountingHole_4_40
J1: AudioJack; Jack_3.5mm_CUI_SJ1-3523N_Horizontal
J2: Speaker; PinHeader_1x02_P2.54mm_Vertical
J3: UART1; PinHeader_1x03_P2.54mm_Vertical
J4: Pot; Testpoint_1x02_P2.54mm
J6: GND; Testpoint_1x02_P2.54mm
J7: DACOUT; Testpoint_1x02_P2.54mm
JP1: TExaS; PinHeader_1x03_P2.54mm_Vertical
R1, R2, R3: 470; R_Axial_DIN0204_L3.6mm_D1.6mm_P7.62mm_Horizontal
R4, R5, R6, R7, R8: 1.5k; R_Axial_DIN0204_L3.6mm_D1.6mm_P7.62mm_Horizontal
R9, R10, R11: 12k; R_Axial_DIN0204_L3.6mm_D1.6mm_P7.62mm_Horizontal
R12, R13, R14, R15, R17: 10k; R_Axial_DIN0204_L3.6mm_D1.6mm_P7.62mm_Horizontal
R16: 20k; R_Axial_DIN0204_L3.6mm_D1.6mm_P7.62mm_Horizontal
RV1: PTA2043; PTA2043pot
SW1: UP; SW_PUSH_6mm
SW2: LEFT; SW_PUSH_6mm
SW3: DOWN; SW_PUSH_6mm
SW4: RGHT; SW_PUSH_6mm
TP1: 3.3V; Testpoint_1x02_P2.54mm
U1: Adafruit ST7735R; adafruit_st7735r2
U2: LP-MSPM0G3507; ti_LP_MSPM0G3507
U3: MCP34119P; DIP-8_W7.62mm_LongPads
U4: HiLetGo_ST7735R; hiletgo_st7735r

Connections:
+3V3: TP1.1 (A), TP1.2 (B), U1.2 (VCC), U1.10 (LITE), U2.J1_1 (+3.3V), U4.2 (VCC), U4.15 (LED+)
+5V: U2.J3_1 (+VBUS)
GND: J3.1 (A), J6.1 (A), J6.2 (B), U1.1 (GND), U2.J2_1 (GND), U2.J3_2 (GND), U4.1 (GND), U4.16 (LED-)
PA8: J3.2 (B), U2.J1_4 (PA8)
PA10: U2.J4_7 (PA10)
PA11: U2.J4_8 (PA11)
PA12: U1.5 (CARD_CS), U2.J4_9 (PA12), U4.14 (SDC_CS)
PA13: U1.4 (D/C), U2.J4_10 (PA13), U4.7 (TFTDC)
PA15: U2.J3_10 (PA15)
PA16: U2.J3_9 (PA16)
PA17: U2.J3_8 (PA17)
PA18: U2.J3_6 (PA18)
PA22: J3.3 (C), U2.J3_4 (PA22)
PA24: U2.J3_7 (PA24)
PA25: U2.J1_2 (PA25)
PA26: U2.J1_5 (PA26)
PA27: U2.J1_8 (PA27)
PA28: U2.J4_3 (PA28)
PA31: U2.J4_4 (PA31)
PB0: U2.J2_9 (PB0)
PB1: U2.J4_2 (PB1)
PB2: U2.J1_9 (PB2)
PB3: U2.J1_10 (PB3)
PB4: U2.J4_1 (PB4)
PB6: U1.6 (TFT_CS), U2.J2_8 (PB6), U4.10 (TFT_CS)
PB7: U1.9 (MISO), U2.J2_7 (PB7), U4.12 (SDC_MISO)
PB8: U1.7 (MOSI), U2.J2_6 (PB8), U4.8 (TFTMOSI), U4.13 (SDC_MOSI)
PB9: U1.8 (SCK), U2.J1_7 (PB9), U4.9 (TFTSCK), U4.11 (SDCSCK)
PB12: U2.J2_2 (PB12)
PB13: U2.J4_6 (PB13)
PB15: U1.3 (RESET), U2.J2_4 (PB15), U4.6 (RESET)
PB16: U2.J2_10 (PB16)
PB17: U2.J2_3 (PB17)
PB18: U2.J3_5 (PB18)
PB19: U2.J3_3 (PB19)
PB20: JP1.2 (C), U2.J4_5 (PB20)
PB23: U2.J1_3 (PA9/PB23)
PB24: U2.J1_6 (PB24)

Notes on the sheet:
U2_Rx
U1_Tx

Board: 2 copper layers, 44 parts (1 on the bottom side), 12 nets, no tracks yet.

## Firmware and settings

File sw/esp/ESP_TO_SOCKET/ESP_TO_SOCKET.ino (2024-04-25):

#include <ESP8266WiFi.h>
#include <stdio.h>
#include <string.h>

// #define     DEBUG1                       // First level of Debug
// #define     DEBUG2                          // Second level of Debug
// #define     DEBUG3                       // Third level of Debug

#define RDY 2                               // GPIO_2
#define SER_BUF_LEN 256                              

char ssid[64] = "<WiFi Name>";
char password[64] = "<WiFi Password>";
char host[16] = "127.0.0.1";
char port[5] = "8080";

char ser_buf[SER_BUF_LEN];
char msg_buf[40];

WiFiClient client;

void setup() {
  // UART Setup
  Serial.begin(9600);                     
  Serial.flush();                           // Empty out anything in buffer
  delay(1000);

  // Setup GPIO
  pinMode(0, INPUT);                        // GPIO_0 Input
  pinMode(2, OUTPUT);                       // GPIO_2 Output
  digitalWrite(RDY, LOW);                   // LOW -> GPIO_2 (Not RDY)

  // Setup WiFi
  Setup_WiFi();                             // Read in SSID, Password
  delay(100);                               // Wait before using WiFi
  digitalWrite(RDY, HIGH);
}


void Setup_WiFi(void) {
  static int bufpos = 0;                // starts the buffer back at the first position in the incoming serial.read

  // Set WiFi to station mode and disconnect from an AP if it was previously connected
  WiFi.mode(WIFI_STA);
  WiFi.disconnect();                        // Disconnect the Wifi before re-enabling it

  // Wait for system to stabilize
  delay(1000);  

  digitalWrite(RDY, HIGH);
  delay(100);                             // Wait before reading

  #ifdef DEBUG1
    Serial.println("Preparing to receive...");
  #endif

  while ((Serial.available() == 0)) {}
  while (Serial.available() > 0)   {
      char inchar = Serial.read();  // assigns one byte (as serial.read()'s only input one byte at a time
      if (inchar != '\n') {         // if the incoming character is not a newline then process byte
        ser_buf[bufpos] = inchar;   // the buffer position in the array get assigned to the current read
        bufpos++;                   // once that has happend the buffer advances, doing this over and over again until the end of package marker is read.
        delay(10);
      }
  }
    
  char pf = 0; //Parse Failed
  if (bufpos  > 0) {
    pf |= get_next_token(ssid,          ser_buf, ",");
    pf |= get_next_token(password,         NULL,    ",");
    pf |= get_next_token(host,         NULL,    ",");
    pf |= get_next_token(port,         NULL,    ",");
 
    for (int i = 0; i < SER_BUF_LEN; i++)  (ser_buf[i]) = 0;
    bufpos = 0;     // Reset buffer pointer
      
    #ifdef DEBUG2
      Serial.println();
      Serial.print(ssid);
      Serial.print(',');
      Serial.print(password);
      Serial.print(',');
      Serial.print(host);
      Serial.print(',');
      Serial.print(port);
      if(pf)
        Serial.print("\nFailed to parse one or more input strings!\n");
    #endif
  }

  // connect to a WiFi network
  WiFi.begin(ssid, password);
  
  #ifdef DEBUG1
    Serial.print("\nConnecting to WiFi..");
  #endif

  while (WiFi.status() != WL_CONNECTED) {
      delay(1000);
      Serial.print(".");                    // Feedback that we are still connecting
  }
  
  #ifdef DEBUG1
    Serial.println("\nConnected to the WiFi network");
  #endif
  
  Serial.flush();

  uint16_t port_num = atoi(port);

  if (!client.connect(host, port_num)) {
    Serial.println("Connection failed");
    delay(5000);
    return;
  }

  #ifdef DEBUG2
    if (client.connected()) {
      client.println("Hello from the ESP8266");
    }

    unsigned long timeout = millis();
    while (client.available() == 0) {
      if (millis() - timeout > 40000) {
        Serial.println(">>> Client Timeout !");
        client.stop();
        delay(10000);
        return ;
      }
    }

    timeout = millis();
    Serial.println("RCV from remote server");
    while (client.available()) {
      char ch = static_cast<char>(client.read());
      Serial.print(ch);

      if (millis() - timeout > 30000) {
        Serial.flush();
        Serial.println("Stopping debugging remote");
      }
    }
  #endif
  Serial.flush();
  digitalWrite(RDY, LOW);                   // Break out of loop in WiFi Setup
}   

// ----------------------------------------------------------------
//  -------     Define Safer tokenizer     ------------------------
// ----------------------------------------------------------------

//Similar to strcpy(dest, strtok(src, delim)); except without hard faults
int get_next_token(char *dest, char *src, const char *delim){
  static char* last_src;

  //Continue with old token string, if a new one is not provided.
  if(src != NULL) last_src = src;

  //Check for failure conditions
  if((dest == NULL) || (last_src == NULL)) return 1;  //Return failure if either of the source pointers are NULL  
  if(last_src[0] == 0x00) return 1;                 //Return failure if the src string is empty

  //Attempt to copy the string by character
  while(true){
    if( last_src[0] == 0x00 ){
      break;                                        //String was 'split' due to the string ending  
    } else if( strchr(delim, last_src[0]) == NULL ){
      
      dest[0] = last_src[0];                        //If a delimiter character is not in this position, copy the char
      dest++;
      last_src++;
    } else {
      dest[0] = 0x00;
      last_src[0] = 0x00;
      last_src++;                                  //Increment the position so in the next call, we are in valid spot.
      break;
    }
  }
  
  return 0; //Success!
}

String getSerialMessage() {
  String message = "";

  while (Serial.available() == 0) {}
  while(1) {
    char incomingChar = Serial.read();
    if (incomingChar == '~') {
      while (Serial.available() == 0) {}
      uint8_t length = (uint8_t) Serial.read();
      while (Serial.available() == 0) {}
      incomingChar = Serial.read();
      if (incomingChar == '@') {
        while (length > 0) {
          while (Serial.available() == 0) {}
          incomingChar = Serial.read();
          message+=incomingChar;
          length--;
        }
        break;
      }
    }
  }
  
  return message;
}

void tm4c2server(String msg) {
  if (client.connected()) {
    client.print(msg);
  }
  else {
    Serial.println("Server communication failed...");
  }
}

String getClientMessage() {
  String message = "";

  while (client.available()) {
      char ch = static_cast<char>(client.read());
      message += ch;
  }

  return message;
}

void server2tm4c(String msg) {
  Serial.flush();
  Serial.print('~');
  Serial.print(msg.length());
  Serial.print('@');
  Serial.print(msg);
}

void loop() {
  if (Serial.available()) {
    // digitalWrite(RDY, LOW);
    String msg = getSerialMessage();
    tm4c2server(msg);
    // digitalWrite(RDY, HIGH);
  }

  if (client.available()) {
    // digitalWrite(RDY, LOW);
    String msg = getClientMessage();
    server2tm4c(msg);
    // digitalWrite(RDY, HIGH);
  }
}

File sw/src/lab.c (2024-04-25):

/**
 * @file        lab.c
 * @author      your name (your_email@doman.com), Jonathan Valvano, Matthew Yu
 *              <TA NAME and LAB SECTION # HERE>
 * @brief       An empty main file for running your lab.
 * @version     0.1.0
 * @date        2022-10-08 <REPLACE WITH DATE OF LAST REVISION>
 * @copyright   Copyright (c) 2022
 * @note        Potential Pinouts:
 *                  Backlight (pin 10) connected to +3.3 V
 *                  MISO (pin 9) unconnected
 *                  SCK (pin 8) connected to PA2 (SSI0Clk)
 *                  MOSI (pin 7) connected to PA5 (SSI0Tx)
 *                  TFT_CS (pin 6) connected to PA3 (SSI0Fss)
 *                  CARD_CS (pin 5) unconnected
 *                  Data/Command (pin 4) connected to PA6 (GPIO)
 *                  RESET (pin 3) connected to PA7 (GPIO)
 *                  VCC (pin 2) connected to +3.3 V
 *                  Gnd (pin 1) connected to ground
 *
 *                  Center of 10k-ohm potentiometer connected to PE2/AIN1
 *                  Bottom of 10k-ohm potentiometer connected to ground
 *                  Top of 10k-ohm potentiometer connected to +3.3V
 *
 *              Warning. Initial code for the RGB driver creates bright flashing
 *              lights. Remove this code and do not run if you have epilepsy.
 */
 
 
//files to include 
/*
main one 
esp base - wifi one - arduino
sockets file - send receive functions in this 
menu file - fsm 
controls file - buttons deals with that 
*/

/** File includes. */
#include <stdint.h>
#include <stdio.h>
#include <string.h>
/* Register definitions. */
#include "./inc/tm4c123gh6pm.h"
/* Clocking. */
#include "./inc/PLL.h"
/* Clock delay and interrupt control. */
#include "./inc/CortexM.h"
/* Initialization of all the pins. */
#include "./inc/Unified_Port_Init.h"
/* Talking to PC via UART. */
#include "./inc/UART.h"
/* ST7735 display. */
#include "ILI9341.h"


/* Add whatever else you need here! */
#include "Switch.h"
#include "Music.h"
#include "../lib/SD/eDisk.h"
#include "../lib/SD/ff.h"
#include "Display.h"
#include "Messages.h"
#include "FSM.h"
#include "./inc/Timer5A.h"
#include "./inc/UART5.h"
#include "./inc/esp8266_base.h"
// port b 6

/** MMAP Pin definitions. */
#define PF0   (*((volatile uint32_t *)0x40025004)) // Left Button
#define PF1   (*((volatile uint32_t *)0x40025008)) // RED LED
#define PF2   (*((volatile uint32_t *)0x40025010)) // BLUE LED
#define PF3   (*((volatile uint32_t *)0x40025020)) // GREEN LED
#define PF4   (*((volatile uint32_t *)0x40025040)) // Right Button
	
void Pause(void);
void DelayWait10ms(uint32_t n);

static FATFS g_sFatFs;
FRESULT MountFresult;


//we are going to have to map the album cover to teh sonsg - we would ahve to use 


int main(void) {
    /* Disable interrupts for initialization. */
    DisableInterrupts();

    /* Initialize clocking. */
    PLL_Init(Bus80MHz);

    /* Allow us to talk to the PC via PuTTy! Check device manager to see which
       COM serial port we are on. The baud rate is 115200 chars/s. */
    UART_Init();
    UART5_Init();
    Reset_8266();
    SetupWiFi();

    /* Initialize all ports. */
    Unified_Port_Init();
	  //SSI2_Init(4);
	//ST7735_InitR(INITR_REDTAB);     // Start up display.
    ILI9341_init();
	//setRotation(3);

    /* Start RGB flashing. WARNING! BRIGHT FLASHING COLORS. DO NOT RUN IF YOU HAVE EPILEPSY. */
    //RGBInit();
		
    /* Initialize buttons */
    switch_init();

    /* Initialize music driver */
    //SongStrIndex = 0;
    music_init();
    message_init();
		
    FSM_Init();

    /* Allows any enabled timers to begin running. */
    EnableInterrupts();
    ILI9341_fillScreen(ILI9341_WHITE);
	

    front8 = Buf2; // buffer being output to DAC
    back8 = Buf;   // buffer being written to from SDC
    Count8 = 0;
    flag8 = 0; // 1 means need data into back
    BufCount8 = 0;
    done_song = 0;
    stop_dac = 0;



    MountFresult = f_mount(&g_sFatFs, "", 0);
    if(MountFresult){
        //ILI9341_DrawString(52, 0, "f_mount error",0x03E0 , 2);
    }
    

    LoadBitmap(Songs[SongStrIndex].album_file);
    replacealbumCover(Get_State().name, false);
    load_song();
    pause_song();

    // Main while loop of system
    while(1){
        //could check if need to draw flag here. If so, Fill screen white
        //set needtoDraw in FSMController when state transitions to a new menu, like all the back button tran
        State_t current_state = Get_State();
        if (get_clear_flag()){
            ILI9341_fillScreen(ILI9341_WHITE);
            replacealbumCover(current_state.name, true);
            set_clear_flag(0);
        }
        switch(current_state.name){
            case menu_mus:
            case menu_msg:
            case menu_play:
            case menu_pl:
            case menu_fa:
            case menu_re:
                drawMainMenu(current_state.name);
                break;
            case song1:
            case song2:
            case song3:
            case song4:
            case song5:
            case song6:
            case song7:
            case mus_pl:
            case mus_fa:
            case mus_re:
            case mus_ba:
                drawMusicPage(current_state.name);
                break;
            case np_pl:
            case np_fa:
            case np_re:
            case np_ba:
                drawNowPlayingPage(current_state.name);
                break;
            case msg_bck:
            case msg_key:
                display_keys();
                break;
        }
        // other tasks
    }
}

/** Function Implementations. */
void DelayWait10ms(uint32_t n) {
    uint32_t volatile time;
    while (n){
        time = 727240 * 2 / 91;  // 10msec
        while (time){
            --time;
        }
        --n;
    }
}

void Pause(void) {
    while (PF4 == 0x00) {
        DelayWait10ms(10);
    }
    while (PF4 == 0x10) {
        DelayWait10ms(10);
    }
}

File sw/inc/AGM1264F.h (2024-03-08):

//*****************AGM1264F.h***************************************
// implementation of the driver for the AGM1264F MODULE
// Jonathan W. Valvano 11/8/11
// modified to run on LM4F120 launchpad on 10/8/12
// compiled on TM4C123 on 9/11/13
// May 2, 2015
/* This example accompanies the book
   "Embedded Systems: Real Time Interfacing to Arm Cortex M Microcontrollers",
   ISBN: 978-1463590154, Jonathan Valvano, copyright (c) 2015

 Copyright 2015 by Jonathan W. Valvano, valvano@mail.utexas.edu
    You may use, edit, run or distribute this file
    as long as the above copyright notice remains
 THIS SOFTWARE IS PROVIDED "AS IS".  NO WARRANTIES, WHETHER EXPRESS, IMPLIED
 OR STATUTORY, INCLUDING, BUT NOT LIMITED TO, IMPLIED WARRANTIES OF
 MERCHANTABILITY AND FITNESS FOR A PARTICULAR PURPOSE APPLY TO THIS SOFTWARE.
 VALVANO SHALL NOT, IN ANY CIRCUMSTANCES, BE LIABLE FOR SPECIAL, INCIDENTAL,
 OR CONSEQUENTIAL DAMAGES, FOR ANY REASON WHATSOEVER.
 For more information about my classes, my research, and my books, see
 http://users.ece.utexas.edu/~valvano/
 */

#pragma once

// Hardware LCD1030 from BG Micro (not tested):
// gnd    =  1- AGM1264F ground
// +5V    =  2- AGM1264F Vcc (with 0.1uF cap to ground)
// pot    =  3- AGM1264F Vo  (center pin of 10k pot)
// PE0    =  4- AGM1264F D/I (0 for command, 1 for data)
// gnd    =  5- AGM1264F R/W (blind cycle synchronization)
// PE1    =  6- AGM1264F E   (1 to latch in data/command)
// PB0    =  7- AGM1264F DB0
// PB1    =  8- AGM1264F DB1
// PB2    =  9- AGM1264F DB2
// PB3    = 10- AGM1264F DB3
// PB4    = 11- AGM1264F DB4
// PB5    = 12- AGM1264F DB5
// PB6    = 13- AGM1264F DB6
// PB7    = 14- AGM1264F DB7
// PE2    = 15- AGM1264F CS1 (controls left half of LCD)
// PE3    = 16- AGM1264F CS2 (controls right half of LCD)
// +5V    = 17- AGM1264F RES (reset)
// pot    = 18- ADM1264F Vee (-10V)
// NC     = 19- A
// NC     = 20- K
// 10k pot from pin 18 to ground, with center to pin 3
// references   http://www.azdisplays.com/prod/g1264f.php
// sample code  http://www.azdisplays.com/PDF/agm1264f_code.pdf
// data sheet   http://www.azdisplays.com/PDF/agm1264f.pdf

// Sparkfun LCD-00710      GDM12864H.pdf 
// HardwareADM12864H (tested):
// +5V    =  1- Vdd
// gnd    =  2- Vss
// pot    =  3- Vo
// PB0    =  4- DB0
// PB1    =  5- DB1
// PB2    =  6- DB2
// PB3    =  7- DB3
// PB4    =  8- DB4
// PB5    =  9- DB5
// PB6    = 10- DB6
// PB7    = 11- DB7
// PE2    = 12- CS2	 (control left side of LCD)
// PE3    = 13- CS1	 (control right side of LCD)
// +5V    = 14- /RES (reset)
// gnd    = 15- R/W (blind cycle synchronization)
// PE0    = 16- D/I (0 for command, 1 for data)
// PE1    = 17- E
// pot    = 18- Vee
// NC     = 19- A
// NC     = 20- K
// 10k pot from pin 18 to ground, with center to pin 3
// http://www.sparkfun.com/datasheets/LCD/GDM12864H.pdf

// BUG NOTICE 11/11/09 -Valvano
// When changing from right to left or from left to right
//   the first write with data=0 goes to two places
// One can reduce the effect of this bug by
// 1) Changing sides less often
// 2) Ignore autoincrement, and set column and page address each time
// 3) Blanking the screen then write 1's to the screen
// GoTo bug fixed on 11/20/09

//******************************************************************


// to use it as an 8-line by 21-character display
// initialize it once using
//      LCD_Init
// clear screen with
//      LCD_Clear
// set cursor position using
//      LCD_GoTo
// place ASCII on the screen using
//      LCD_OutChar
//      LCD_OutString
//      LCD_OutDec
//      LCD_OutFix1
//      LCD_OutFix2
//      LCD_OutFix3

// ********* LCD_Init***********
// Initialize AGM1264F 128-bit by 64-bit graphics display
// activates SysTick at 50 MHz, assumes PLL active
// Input: none
// Output: none
// does not clear the display
void LCD_Init(void);

// ********* LCD_Clear***********
// Clear the entire 1024 byte (8192 bit) image on the
//    AGM1264F 128-bit by 64-bit graphics display
// Input: value to write into all bytes of display RAM
// Output: none
// e.g., LCD_Clear(0);  // makes all pixels off
void LCD_Clear(unsigned char data);

//-----------------------LCD_GoTo-----------------------
// Move cursor
// Input: line number is 1 to 8, column from 1 to 21
// Output: none
// errors: it will ignore legal addresses
void LCD_GoTo(int line, int column);

// ********* LCD_OutChar***********
// Output ASCII character on the
//    AGM1264F 128-bit by 64-bit graphics display
// Input: 7-bit ASCII to display
// Output: none
// letter must be between 32 and 127 inclusive
// execute LCD_GoTo to specify cursor location
void LCD_OutChar(unsigned char letter);

//---------------------LCD_OutString--------------
// Display String
// Input: pointer to NULL-terminationed ASCII string
// Output: none
void LCD_OutString(char *pt);

//-----------------------LCD_OutDec-----------------------
// Output a 16-bit number in unsigned decimal format
// Input: 16-bit unsigned number
// Output: none
// fixed size 5 digits of output, right justified
void LCD_OutDec(unsigned short n);

//-----------------------LCD_OutSDec-----------------------
// Output a 16-bit number in signed decimal format
// Input: 16-bit signed number
// Output: none
// fixed size 6 digits of output, right justified
void LCD_OutSDec(short n);

//-----------------------LCD_OutFix1-----------------------
// Output a 16-bit number in unsigned decimal fixed-point
// with resolution = 0.1
// Input: 16-bit unsigned number
// Output: none
// fixed size is 6 characters of output, right justified
// if input is 12345, then display is 1234.5
void LCD_OutFix1(unsigned short n);

//-----------------------LCD_OutFix2-----------------------
// Output a 16-bit number in unsigned decimal fixed-point
// with resolution = 0.01
// Input: 16-bit unsigned number
// Output: none
// fixed size is 6 characters of output, right justified
// if input is 12345, then display is 123.45
void LCD_OutFix2(unsigned short n);

//-----------------------LCD_OutFix2b-----------------------
// Output a 16-bit number in unsigned decimal fixed-point
// with resolution = 0.01
// Input: 16-bit unsigned number, 0 to 9999
// Output: none
// fixed size is 5 characters of output, right justified
// if input is 2345, then display is 23.45
void LCD_OutFix2b(unsigned short n);

//-----------------------LCD_OutFix3-----------------------
// Output a 16-bit number in unsigned decimal fixed-point
// with resolution = 0.001
// Input: 16-bit unsigned number
// Output: none
// fixed size is 6 characters of output, right justified
// if input is 12345, then display is 12.345
void LCD_OutFix3(unsigned short n);
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

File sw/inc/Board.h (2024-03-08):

// Board.h
// Runs on LM4F120/TM4C123
// Provide functions that initialize a GPIO as an input pin and
// allow reading of two negative logic switches on PF0 and PF4
// and an external switch on PA5.
// Use bit-banded I/O.
// Daniel and Jonathan Valvano
// September 12, 2013

/* This example accompanies the book
   "Embedded Systems: Introduction to ARM Cortex M Microcontrollers",
   ISBN: 978-1469998749, Jonathan Valvano, copyright (c) 2015
   Section 4.2    Program 4.2

  "Embedded Systems: Real Time Interfacing to ARM Cortex M Microcontrollers",
   ISBN: 978-1463590154, Jonathan Valvano, copyright (c) 2015
   Example 2.3, Program 2.9, Figure 2.36

 Copyright 2015 by Jonathan W. Valvano, valvano@mail.utexas.edu
    You may use, edit, run or distribute this file
    as long as the above copyright notice remains
 THIS SOFTWARE IS PROVIDED "AS IS".  NO WARRANTIES, WHETHER EXPRESS, IMPLIED
 OR STATUTORY, INCLUDING, BUT NOT LIMITED TO, IMPLIED WARRANTIES OF
 MERCHANTABILITY AND FITNESS FOR A PARTICULAR PURPOSE APPLY TO THIS SOFTWARE.
 VALVANO SHALL NOT, IN ANY CIRCUMSTANCES, BE LIABLE FOR SPECIAL, INCIDENTAL,
 OR CONSEQUENTIAL DAMAGES, FOR ANY REASON WHATSOEVER.
 For more information about my classes, my research, and my books, see
 http://users.ece.utexas.edu/~valvano/
 */
#pragma once

// negative logic switches connected to PF0 and PF4 on the Launchpad
// red LED connected to PF1 on the Launchpad
// blue LED connected to PF2 on the Launchpad
// green LED connected to PF3 on the Launchpad
// NOTE: The NMI (non-maskable interrupt) is on PF0.  That means that
// the Alternate Function Select, Pull-Up Resistor, Pull-Down Resistor,
// and Digital Enable are all locked for PF0 until a value of 0x4C4F434B
// is written to the Port F GPIO Lock Register.  After Port F is
// unlocked, bit 0 of the Port F GPIO Commit Register must be set to
// allow access to PF0's control registers.  On the LM4F120, the other
// bits of the Port F GPIO Commit Register are hard-wired to 1, meaning
// that the rest of Port F can always be freely re-configured at any
// time.  Requiring this procedure makes it unlikely to accidentally
// re-configure the JTAG and NMI pins as GPIO, which can lock the
// debugger out of the processor and make it permanently unable to be
// debugged or re-programmed.

//------------Switch_Init------------
// Initialize GPIO Port A bit 5 for input.
// Input: none
// Output: none
void Switch_Init(void);

//------------Switch_Input------------
// Read and return the status of GPIO Port A bit 5.
// Input: none
// Output: 0x20 if PA5 is high
//         0x00 if PA5 is low
uint32_t Switch_Input(void);

//------------Board_Init------------
// Initialize GPIO Port F for negative logic switches on PF0 and
// PF4 as the Launchpad is wired.  Weak internal pull-up
// resistors are enabled, and the NMI functionality on PF0 is
// disabled.
// Input: none
// Output: none
void Board_Init(void);

//------------Board_Input------------
// Read and return the status of the switches.
// Input: none
// Output: 0x01 if only Switch 1 is pressed
//         0x10 if only Switch 2 is pressed
//         0x00 if both switches are pressed
//         0x11 if no switches are pressed
uint32_t Board_Input(void);

// Program 2.9 from Volume 2
//------------Switch_Init3------------
// Initialize GPIO Port B bit 1 for input.
// Input: none
// Output: none
void Switch_Init3(void);
//------------Switch_Input3------------
// Read and return the status of GPIO Port B bit 1.
// Input: none
// Output: 0x02 if PB1 is high
//         0x00 if PB1 is low
uint32_t Switch_Input3(void); 

//------------Switch_Debounce------------
// Read and return the status of the switch 
// Input: none
// Output: 0x02 if PB1 is high
//         0x00 if PB1 is low
// debounces switch
uint32_t Switch_Debounce(void);

//------------Switch_Debounce------------
// wait for the switch to be touched 
// Input: none
// Output: none
// debounces switch
void Switch_WaitForTouch(void);

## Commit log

2024-03-22 slight edit schematic
    [baseline_project.kicad_sch]
2024-03-26 Play short wav file; temporary functionality
    [DAC.c, Switch.c, lab.c]
2024-03-26 schematic done, pcb design
    [baseline_project.kicad_pcb, baseline_project.kicad_sch]
2024-03-27 placement ST7735 board
    [baseline_project.kicad_pcb, baseline_project.kicad_sch]
2024-03-27 Filling out Switch functions; still needs work
2024-03-28 routed ST7735
    [baseline_project.kicad_pcb]
2024-03-28 Edge-Triggered Interrupts on PC4,5,6,7 and PF4
2024-03-28 Defined music driver
2024-03-29 Music driver
2024-03-29 Minor fixes to music driver
    [Music.c, Switch.c, lab.c]
2024-03-29 before changing display
    [baseline_project.csv, baseline_project.kicad_pcb, baseline_project.kicad_sch]
2024-03-29 so far so good new display pcb
    [baseline_project.kicad_pcb, baseline_project.kicad_sch]
2024-03-29 pcb done
    [baseline_project.kicad_pcb]
2024-03-29 pcb and lab 7 report done
    [BOM.csv, BOM.xlsx, ps33536_hjs2235_shp695_wtc534.kicad_pcb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]
2024-04-02 final pcb submission
    [bom.csv, designators.csv, positions.csv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]
2024-04-02 ESP-Socket baseline
2024-04-02 Baseline socket
2024-04-17 most Display driver functions are finished - need to work on drawChar and drawString
2024-04-23 fixed colors; added function for changing bg color
    [ILI9341.c, lab.c]
2024-04-23 can move around keyboard, need to fix x/y
    [Switch.c, lab.c]
2024-04-24 moved Pages to display; fixed warning in eDisk
    [Music.c, lab.c]
2024-04-24 fixed out of space error
    [lab.c]
2024-04-25 More WiFi merge conflict issues
    [ESP_TO_SOCKET.ino]
